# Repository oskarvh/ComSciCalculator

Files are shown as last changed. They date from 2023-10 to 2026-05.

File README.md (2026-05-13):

# Computer Scientist Calculator

The computer scientist calculator (comSciCalc) is a modern take on the HP 16C. 
It was born out of frustration of the terrible windows calculator, and the lack of nice alternatives. 

The comSciCalc consists of both hardware and software, where each component can be used independently or together; The hardware can act as a controller for the software, in which case the software is simply acting as a bigger display. 

## Setup
A list of the dependencies are shown below, divided into common dependencies, software (PC) dependencies and firmware dependencies for building, testing and running.

Apart from the non-source-code (e.g. compilers, python etc), all dependencies are pulled in either via git submodules (`git clone --recurse-submodules git@github.com:oskarvh/ComSciCalculator.git`), or at build time using CMake's `FetchContent` module.

### Common Dependencies
The common dependencies needs to be installed separately. 
- CMake version 3.27.7 or newer (`apt install cmake`)
- clang-format version 14.0.0 (`sudo apt install clang-format`)
- Doxygen 1.9.6 (`sudo apt install doxygen`)
- arm-none-eabi-gcc: Arm GNU Toolchain 13.3.1 or other compatible with rp2040 (`sudo apt install cmake gcc-arm-none-eabi libnewlib-arm-none-eabi build-essential`)
- CMake Tools (not required, but recommended if using VSCode)
- Python 3.10 or newer, with venv support (`apt install python3.<version>-venv`)

### Firmware Dependencies
- `arm-none-eabi` Compiler for the rp2040 (`sudo apt install gcc-arm-none-eabi libnewlib-arm-none-eabi build-essential`). Dependencies vary on system, see the [RPi Pico User Guide](https://datasheets.raspberrypi.com/pico/getting-started-with-pico.pdf)
- [OpenOCD for RP2040](https://github.com/raspberrypi/openocd) OpenOCD for RP2040. Unfortunately, the rp2040 requires its own installation of OpenOCD. See [this guide](https://github.com/SuperChange001/pico_debug_with_swd) for installation.
These dependencies are downloaded via CMake.
- [RP2040 Pico-SDK library](https://github.com/raspberrypi/pico-sdk) (included as a submodule)
- [Clay](https://github.com/oskarvh/clay) Forked Clay (C Layout) library with support for FT81x (included as submodule). Used both for PC and embedded GUI
- [FT800-FT813 library](https://github.com/RudolphRiedel/FT800-FT813) (included as a submodule)
- ComSciCalc Hardware

### Software Dependencies
These dependencies should be linked via CMake files and/or submodules.
- [Clay](https://github.com/oskarvh/clay) Forked Clay (C Layout) library with support for FT81x (included as submodule). Used both for PC and embedded GUI

### Test Dependencies
These dependencies are either included via Python or via submodules.
- Pytest
- [Unity](git@github.com:ThrowTheSwitch/Unity.git) Unity test tool (to be deprecated)
## BUILD
There are several targets that can be built in this repository:
- Firmware
- Software
- Tests
## Directory Structure
A brief overview of the directory structure can be found in this section. 

### `comSciCalcLib/`
This directory contains the comSciCalc library. This is technically a common library used here, but it has its own directory for clarity, since this is an essential part of the project. 

### `firmware/`
The firmware directory contains code required to build the firmware running on the comSciCalc hardware.
Note that this pulls in common dependencies as well. 
### `software/`
The software directory contains the code required to build the PC software. This uses some of the dependencies common to the firmware as well. 
### `test/`
The test directory contains all tests used both with firmware and software. 
Tests are divided into several categories.
#### `test/unit_tests/`
This directory contains unit tests, aimed to test granular components of the comSciCalc. 

If a new calculation function is added to the comSciCalc, then a unit test shall be written for that function. 
#### `test/feature_tests/`
This directory contains feature tests. These tests are aimed to test higher level functions of the comSciCalc, such as the solver and formatters. 

If a new high level feature is added in comSciCalc is created, then a feature test is expected.
#### `test/integration_tests/`
This is the highest level tests, where hardware and/or software is expected in the loop. 

If a new hardware revision is introduced which update interfaces, or if new high level functionality is created, a new integration test shall be written/existing test case updated.

### `utils/`
This is the utilities directory, and contain code which is not compiled/run/used at normal build time. For example, for creating bit-maps of fonts for the firmware, or other utilities which output is aimed at being checked in rather than built.

This directory is included as a developer help tool. 

### `hardware/`
This directory contain all the hardware source files, such as PCB design, mechanical design etc.

### `common/`
This directory contains code used in both `firmware/` and `software/`, and is placed outside either directory to have a common source, such that changes are reflected in both the firmware and the software. 

An example of this is the GUI, the link layer protocols etc. 

### `html/`
This directory contains the generated Doxygen HTML files. This is updated on a release basis, since the doxygen can be generated. Hence, it's not checked in regularly. 

## Contributing
Contributions are welcome, and this section aims to help a developer to add functionality to the comSciCalc.

There are several parts to the comSciCalc, and it's built with the aim of easily being able to add new features, such as new mathmatical operators.

### Adding an operator
An operator is any mathmatical function that can be called by the calculator, e.g. `+` or `AND()` etc.
An operator can have one or several arguments. 

# TODO list
This section contains stuff that needs doing. 
- Finish the documentation
- Restructure the repo to align with the structure in this readme.

---
# OLD STUFF (KEPT FOR REFERENCE, TO BE DELETED)
---
## Status of project
The software is mostly being worked on at the moment. A few iterations 
of the hardware has been made, but nothing has been ordered yet because some components are hard to get at the moment, along with the continuous change of heart when it comes to the hardware specs. 

The software is in a semi-stable phase at the moment. The core of the 
calculator, the software/comSciCalc_lib has had the ground work made. 
Fluffy features such as [doxygen](https://www.doxygen.nl/) and 
[clang formatter](https://clang.llvm.org/docs/ClangFormat.html) has been added as well. 

Unit testing has begun using the [Unity framework](https://github.com/ThrowTheSwitch/Unity). 

## Software

The software folder consists of two major code bases: comSciCalc_lib and unit_tests. 

The comSciCalc_lib is a library, currently compiled with GCC, which contains all the 
functions needed to input data, calculate and output result and formatted input. To 
compile and run the unit tests, run the following script:
```bash
./software/run_unit_tests.sh
```
To run the script in verbose mode, add the -V flag. To not compile the source, 
use flag -d. 
Incorrext flags will prompt the usage message:
```bash
$ ./run_unit_tests.sh -h
Usage: ./run_unit_tests.sh [-V verbose] [-d dont clean]
```
This will compile the comSciCalc_lib library and the unit test code (using Unity test framework) and run the tests. 

This very same library is intended to work on an embedded system, along with (hopefully) a 
PC GUI of sorts, so the code does not implement any fancy features. 

However, the test code uses some GCC specific preprocessor routines to initialize some of 
the arrays. 
## Software dependencies
On Windows 10, I am using :
* gcc (MinGW.org GCC-6.3.0-1) 6.3.0
* Clang version 12.0.0
* Doxygen 1.9.6
* Git bash

To pull unity into the repo, run:
```bash
git submodule update --init
```
## Documentation
To generate the docs, run the following:
```bash
cd software # Go to the software dir. 
doxygen doxygen_config
```
And the docs can be found in software/html/index.html

## Technical jargon
The core functionality of the calculator is: 
1. Handling input (valid checks, insertion)
2. Printing input
3. Converting from text to something that can be solved. 

Going through the list above, the input handling is done using a doubly linked
list, where the incoming char will be placed. Each entry has a pointer to 
the previous and a pointer to the next entry, along with data and meta data 
for that entry. The data is the actual input character, where the accepted chars
are a union between numerical and non-numerical input [0-9,a-f,(,),','] and
chars specific to the operators, found in comscicalc_operators.c. 

The meta data consists of e.g. base (i.e. hex, dec, bin), type of entry, pointer
to operator function (see below) and some more. See the docs for more info. 

Each operator has a unique char associated with it, along with some meta data of
its own, and a pointer to the function implementing the operator. 
The function is linked via function pointer that are casted left and right, 
but due to the way C let's a code handle pointer willy-nilly, this works out fine. 

When an input list is solved, it will re-use the entry list type above, but 
then each entry has a number associated with it, instead of a char. 
The solver will then go through this list and solve based on the function 
pointers and numbers entered. The next section will explain how to add 
a new operator. 

## Adding new operators
A new operator is added in the comscicalc_operators.[c,h] files, by adding a 
new entry to the ```operators``` table. The entry must consist of the following:
```
.inputChar = /* Associated operator character , e.g. '+'*/,
.opString = /* Null terminated string to be displayed during printing.  "+\0"*/,
.solvPrio = /* Solving priority, 0 is the highest. (see docs) */,
.bIncDepth = /* Boolean indicating if operators increase depth (=should it invoke a bracket) */,
.numArgs = /* Number of arguments. -1 if variable. Must be 2 if not depth increasing.  */,
.pFun = /* Pointer to the function associated with the operator */
```
Moreover, the operator function needs to be added to the comscicalc_operators.c 
and comscicalc_operators.h file as well. The operator function must follow this
 format:
 ```
int8_t calc_<NAME>(SUBRESULT_UINT *pResult, inputFormat_t inputFormat, int num_args, SUBRESULT_UINT *args);
 ```
Ideally the operator should support fixed and floating point, along with signed
and unsigned integer formats. But if for some reason this is impossible, then 
the function must return ```format_not_supported```

## Test coverage
The ```software/test_coverage.sh``` script will run a gcov analysis of the two main
library files: ```comscicalc.c``` and ```comscicalc_operators.c``` when running the test suite
in order to see what the code coverage is during the tests. This should ideally 
be close to 100% as it would indicate the code coverage is complete. 

Running this script will make a temporary folder under software called 
test_coverage, where the build files, gcov files and copies of the source files
are stored. 

Moreover, the script will print the code coverage for the two files being analyzed. 

To check which lines are being covered, run the ```test_coverage.sh``` script, go into the test_coverage directory and take a look in the ```*.c.gcov``` files. 
Each line with a ```#####``` mark has not been executed. 

With that information, additional tests can be added to the test suite to
ensure as good test coverage as possible.

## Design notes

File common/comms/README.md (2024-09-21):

# Computer Scientist Calculator Communication Protocol

This directory contains the unified communications protocol used by
the comSciCalc and PC software, where the units are assumed to be connected
by serial interface, e.g., UART or USB VCOM. 

## Background
The serial interface enables two-way communication between the host (computer) and the device (calculator). In the interest of not blasting the host with unwanted information, the device shall not communicate the state unless the host has explicitly connected to the device. 

Hence, there is a set of messages required to facilitate connection and disconnection between the host and the device. 

The intended host applications are: 
* PC GUI
* Hardware-in-the-loop feature testing

Once the device is connected to the host, there are multiple states and/or events that are allowed, for which the base set of changing settings and communicating with the solver are required. 
Since the calculator supports both user defined functions and programs, there is going to be a limit as to what the protocol can support, especially in regards to custom programs. 
As a guide, there shall be a set of graphical functions that will be supported, but there is no requirement for the user to only use these for a custom function. However, if those functions are used, the protocol shall allow compatibility with them. 

## Software stack
The OSI stack model for this interface is shown in Figure 1 below. 

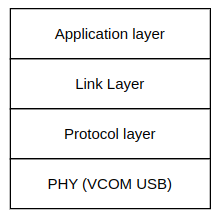
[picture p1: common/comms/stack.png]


*Figure 1. OSI stack model.*

The PHY is simply the USB VCOM layer, and is not specific in this document. 

The protocol layer specifies how the message bytes are arranged, and how the data and metadata is transferred between host and device. 

The link layer focuses on the body of the protocol layer message, and specifies how the binary data is decoded. 

Finally, the application layer is a purely software defined layer which consumes the link layer data, where the data itself is decoded. 

# Protocol Layer
This section documents the protocol and messages used by the serial interface. 
The message structure is shown in Figure 2 below. 

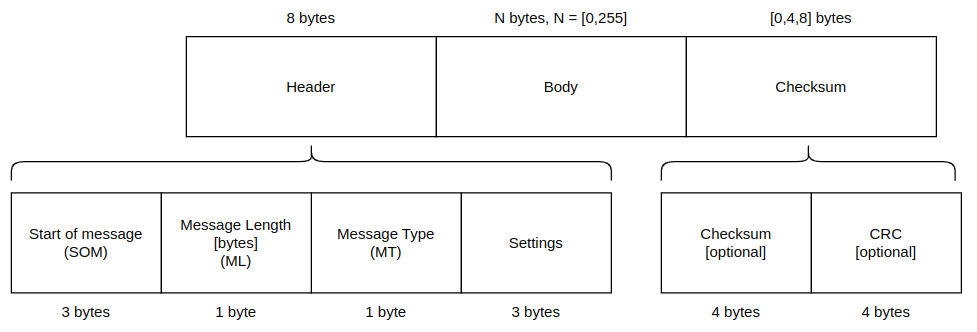
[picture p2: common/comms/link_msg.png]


*Figure 2. Message structure.*

As seen in Figure 2, the header consists of four fields, where the SOM indicates the start of communication. Since the device supports regular ASCII communication via a virtual COM port, to support context switching from ASCII reception to receiving this protocol, an [escape sequence](https://en.wikipedia.org/wiki/ANSI_escape_code) is used to differentiate the two. 
The APC (0x1B 5F 9F) sequence is re-used here, since it’s rarely implemented and can therefore easily be differentiated from other escape sequences. This field is not variable. 

The message length is indicating the length of the body, which is the data containing the message itself. Note that it’s indicating only the body length, not including the header or checksum. 

The message type indicates the type of message being sent (duh), where the message type indicates if the received message is a connection event, ack, data transfer etc.

The three byte settings field is partly used to indicate the settings used for the message, e.g., checksum configuration, body encoding and more, along with byte padding for the body. 

The body is the data itself, and the length in bytes of the data is decided by the ML field. From the protocol side, the body is handled just as binary data without any indications as to where that data is used, so the protocol does not differentiate depending on what data is being transferred. 

Finally, the checksum has two optional fields: Checksum and CRC, where either can be used. Both the checksum and CRC include both header and body. 

This format is used both from the host to device, and from device to host.

See Table 1 below for an overview of the different fields. 

*Table 1. OVerview of different fields*
Field | Accepted value(s) | Description
|:------ |:-----------| :---------------------------------------------------:|
SOM    | `0x1B5F9F` |   Start Of Message: This is a fixed value and <br>indicates the start of a message if prior <br>message has been terminated, or if timeout has been reached. 
ML | 0-255 | Message Length: Body length in Bytes
MT | `0x01` Data Transfer <br> `0x02` ACK <br>`0x04` NACK <br> `0x08` Retransmission <br>`0xF0` Reserved|Message Type: Type(s) of messages. A combination (OR) of the types are available. <br>Data Transfer: Transfer of data. Data will be forwarded to the link layer. <br>ACK: Acknowledgement. <br>NACK: Negative Acknowledgement.<br>Retransmission: This message is a retransmission of a previous message.
Settings | `0x000001` Use Checksum<br>`0x000002` Use CRC<br>`0x0000X0` Timeout<br>`0x000X00` Retries<br>`0xFF9004` Reserved<br> | Settings: These fields are bitwise ORed, and indicate protocol layer settings 
Body|Any|Data packets
Checksum|Any|Checksum (algorithm TBD)
CRC|Any|CRC (algorithm TBD)

## Message Types
The message types indicate the message being sent, and a message containing data can also contain information regarding the last message(ACK,NACK). 

### Data Transfer
If the message type is data transfer, it is assumed but not guaranteed that the body contains data. However, if the data transfer bit is 0, the body must be empty.

### Acknowledgement
If the message type ACK bit is set, it means that the last message was received correctly. If no previous message exists (e.g. connection event), the ACK and NACK can be set to 0. 
The NACK bit aims to indicate that the last message sent had an error. This could indicate that the connection was severed or interrupted, CRC error or any other error corrupting the last message. 

Note that a data transfer can contain an ACK or NACK, meaning that the reception of a message containing data can acknowledge the previous message sent.

A received ACK or NACK is always in relation to the last transmitted message, so full duplex support is limited. Each message must be acknowledged before the next message can be transmitted. 

### Retransmission
If a NACK is received, the transmitter shall retransmit the previous message with the retransmission bit set. Retransmission of the previous message shall be supported by both the device and host. 
The retransmission needs to be acknowledged just like any data transfer, and the bit only indicates that a retransmission is occurring. 

Note that retransmissions here are only valid for issues on the protocol layer, and do not need to be communicated from the link layer. If the link layer needs a retransmission, it has the capability to request it as well, but that is not covered here.

## Settings
The settings simply indicate the settings to be used for the packet. 

### Use Checksum
If “use checksum” is set, then checksum shall be transmitted, received and checked on 
reception. A faulty received checksum shall produce a NACK on the next transmitted message. 

### Use CRC
If “use CRC” is set, then CRCll be transmitted, received and checked on 
reception. A faulty received CRC which cannot recover the data shall produce a NACK on the next transmitted message. 

### Timeout
The timeout section indicates the time to wait for an acknowledgement. No new message can be transmitted until the previous message has been acknowledged, so a timeout event is treated as a NACK. The values in the timeout field are in relation to the LUT in Table 2 below, and as seen the timeout value increases with a factor 10 per value of bits 0-3, and bits 4-15 indicate the multiplier. The final timeout value is the multiplier times the base. 
E.g. 50 ms is multiplier 5 and base 10 ms. 

*Table 2. Timeout bases and multipliers*
Timeout setting value | Timeout
|:------------------- | :-----------:|
Bits 0-3: `0x0`         | base: 1 ms
Bits 0-3: `0x1`         |base: 10 ms
Bits 0-3: `0x2`         |base: 100 ms
Bits 0-3: `0x3`         |base: 1000 ms
Bits 4-15: `0x1`        |multiplier: 1
Bits 4-15: `0x2`        |multiplier: 2
Bits 4-15: `0x3`        |multiplier: 3
Bits 4-15: `0x4`        |multiplier: 4
Bits 4-15: `0x5`        |multiplier: 5
Bits 4-15: `0x6`        |multiplier: 6
Bits 4-15: `0x7`        |multiplier: 7
Bits 4-15: `0x8`        |multiplier: 8
Bits 4-15: `0x9`        |multiplier: 9
Bits 4-15: `0xA-0xC`    |Reserved

The timeout is on a per message basis, so the transmitter tells how long it will wait for an acknowledgement. There is no algorithm for setting this rate based on retransmission, other than it should be set to as low as possible without causing retransmissions. 

### Retries
Retries simply indicate how many retransmissions can be made before a connection is severed. 
If the retries number messages are not successfully acknowledged, the connection is assumed to be severed, and a connection event is required to establish a new connection. 

As of writing this spec, the default number of retries is set to be 3. 
If a retransmission is made, either by NACK or timeout, this field decreases, and if retries = 0 and the message is not ACKed, the connection will be severed. 
It is also a good idea, although not enforced, to increase the timeout per decrementation of this field. This feature is left to the implementer. 

## Data Flow
The protocol itself, i.e. how data is flowing back and forth, is really very simple as it’s done over cable, meaning that it can be assumed that the packet loss is very small. 
There is no guarantee that data will arrive, nor arrive in sequence, but since it’s a point to point protocol that can easily be kept track of by the devices themselves. Since no PHY level interaction is available, ready to send and ready to receive can be assumed to be handled by the PHY already. Moreover, it is assumed that both host and device have sufficiently large receive buffers to hold a message while it’s being received. 

The following sections explain connection, disconnection, retransmission and regular transmission. 
Note that even though the physical layer might support full duplex, this protocol does not support full duplex, rather it’s simplex, where a receiver can assume to empty its receive buffer after a successful reception, and not lose any incoming messages. 

The protocol layer receives byte-per-byte, where it’s considered the largest byte to be first. So the first byte being received in any transmission is the SOM escape (27) byte. 

### Connection event
A connection can be initiated by any device, and is indicated by the initiator sending a message with data transfer = 0, ack = 0 and nack = 0. 
A connection is created if the initiator receives an acknowledged message (ACK=1, NACK=0) within the timeout period. 
Note that the connection by the responder is allowed to contain data. 

A connection event is the only message that can be transmitted without either an ACK or NACK, all messages after the initiator message must contain ACK or NACK. 

The retries section is not required to decrement if the initiator resends the connection event message. 

If a connection event message is NACKed, a connection cannot be made, and the initiator can retry. 

### Disconnection
A disconnection does not have a specified sequence, rather, if the retries counter expires (i.e. a message sent with retries = 0 is not ACKed), the connection is severed. So to sever a connection a device simply needs to stop responding, or NACK the number of retries. 

### Retransmission 
A retransmission shall happen after a message was unsuccessfully received, either by not being ACKed within the timeout, or not receiving a message within the specified timeout. 
If a retransmission is made, the retry counter shall be decremented. If a message is sent with retries = 0, and not ACKed, the connection is severed and the message cannot be assumed to be received. 
If a retransmission is ACKed, the retries counter can be reset to the default value. 

If a lot of retransmissions are observed, then it could be a good idea to increase the timeout, but it’s not enforced. 

### Timeout
A timeout is signified by a message not being received within the timeout period, as specified in the settings section. 

The time is counted from when the transmission is completed, i.e. the last bit is sent to the PHY layer, until the next header has been fully received. Note that the body does not need to be received to stop the timeout timer, since the body has variable length, while the header has a fixed length and is therefore more deterministic. 

Note that any reception of a header will stop the timer, so if the header includes an error it does not count towards a timeout error. Another way of looking at timeout is that the timeout timer shall stop after 8 bytes have been received.

### Inability to receive data
If the data receive queue is full, the protocol layer shall treat this as an inability to receive messages, meaning that if data is dropped due to insufficient queue space, a NACK is sent and the previous message is retransmitted and the queueing is retried the next time that same message is received. 
Inability to receive data due to queue size issues can cause a severed connection. 

### Idle data transmission
If no data is available in the transmission queue, then no data will be sent with the next message at the time of evaluating. 

If there is no data transmitted for a duration of time, i.e. the device and host are both idle, the timeout can be extended such that less data is being sent over the physical layer.
Since the timeout is decided by the transmitted message, the transmitter decides what the timeout should be, so some preemption can be made here. 
The receiver is allowed to wait to transmit a response, as long as it’s within the timeout.

# Link Layer (WIP)
The link layer focuses on the data of the packet, i.e. the body of the protocol layer. 
The link layer receives data from the protocol layer, but does not have control over the protocol layer, so cannot request retransmissions by the protocol layer. 
However, the protocol layer tries its best to verify that all bytes have been received, such that the integrity of the data received by the link layer is good. 
It’s not foolproof but the checksum and CRC should indicate that the received data is at least intact. 
The protocol layer does not guarantee that the received data is sequential though, so steps have to be taken in the link layer to request retransmissions if needed. 

Note that the link layer and protocol layer is separated such that the link layer is protocol agnostic, and it is simply a way of translating the data from just received bits into something that can be used by the comSciCalc device and host. 
Hence, the link layer cannot have any say into what the protocol layer is doing here, and should there be an update in the protocol layer, or change of protocol overall, the link layer should be reusable. 

The link layer data consists of two parts: a header and the raw data itself, and as opposed to the link layer/protocol layer separation, the link layer and application layer does not easily separate. This is due to the construction of the link layer header. 

The link layer receives the significant byte first from the protocol layer, or if received as a pointer, the pointer points to the start of the header. 
Hence, the link layer receives data and length of that data from the protocol layer, and can read the data. There is no flow control between the protocol layer and link layer, other than what can be facilitated by regular queues. 
Moreover, transmissions from the link layer can be handled by queues, not specified here, although with the current implementation of the comSciCalc firmware it’s using FreeRTOS.
The queue size is fixed at compile time, and shared between the protocol layer and link layer. 

## Header
The header decides what the intention of the data is, and thereby how it should be decoded. 
Data here can be, per default, any one of the following types:
* ComSciCalc State
  * Always sent from the device to the host
  * This is mainly aimed to mirror the screen on the calculator to the PC
* ComSciCalc input
  * Always sent from the host to the device
  * This is input to the calculator, in the form of numbers
* Request for data
  * This is a request for the devices internal states
  * This can be used to synchronize the device and the host
* Response for data
  * This is the response for the request
* New program
  * There is space in the flash for custom programs, accessible via the menu
  * This command sends the binary data and where to store it, along with metadata such that the program can be accessible via the menu.

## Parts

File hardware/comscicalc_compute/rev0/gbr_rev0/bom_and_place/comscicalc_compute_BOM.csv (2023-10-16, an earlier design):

Comment | Designator | Footprint | LCSC
22pF | C1,C7 | Capacitor_SMD:C_0402_1005Metric | C1555
10uF | C12,C19,C25 | Capacitor_SMD:C_0805_2012Metric | C15850
22uF | C13,C15,C16,C17,C24,C27,C29 | Capacitor_SMD:C_0805_2012Metric | C45783
1uF | C14 | Capacitor_SMD:C_0603_1608Metric | C15849
100nF | C2,C3,C4,C5,C6,C8,C9,C10,C11,C18,C21,C23,C31,C33,C34,C35,C36 | Capacitor_SMD:C_0402_1005Metric | C1525
4.7uF | C20,C32 | Capacitor_SMD:C_0603_1608Metric | C19666
10nF | C22,C26,C28,C30 | Capacitor_SMD:C_0402_1005Metric | C15195
NSR0240P2T5G | D1 | SamacSys_Parts:SODFL1006X40N | C896425
BLM21PG300SN1D | FB1,FB2 | Resistor_SMD:R_0805_2012Metric | C16903
ACM2012-361-2P-T002 | FL1 | SamacSys_Parts:ACM20121022PT001 | C87126
R7FA4M3AF3CFM#AA0 | IC1 | SamacSys_Parts:QFP50P1200X1200X170-64N | C3230355
TPS92360DCKR | IC2 | SOT65P210X110-5N | C2928788
AP62300TWU-7 | IC3 | SOT95P280X100-6N | C1883519
FT811Q-T | IC4 | SamacSys_Parts:QFN50P700X700X90-49N-D | C3823896
Conn_02x14_Odd_Even | J1,J2 | Connector_PinHeader_2.54mm:PinHeader_2x14_P2.54mm_Vertical_SMD | DNM
USB4110-GF-A | J3 | USB4110GFA | C5143397
4-1734839-0 | J4 | SamacSys_Parts:4-1734839-0 | C590939
ASPI-0403S-1R5M-T | L1 | SamacSys_Parts:ASPI0403S332MT | C187216
3.3uH | L2 | VLS5045EX-3R3N:IND_VLS5045EX-3R3N | C307875
DNM | R1,R2,R9,R10,R11,R12,R13,R23,R50 | Resistor_SMD:R_0402_1005Metric | DNM
5.1k | R14,R18 | Resistor_SMD:R_0402_1005Metric | C258132
22R | R15 | Resistor_SMD:R_0402_1005Metric | C25092
33.2k | R16 | Resistor_SMD:R_0402_1005Metric | C400623
33R | R25,R26,R27,R28,R29,R30,R31,R32,R33,R34,R35,R36,R38,R39,R40,R41,R42,R43,R44,R45,R46,R47,R48 | Resistor_SMD:R_0402_1005Metric | C25105
0R | R3,R7,R22,R37 | Resistor_SMD:R_0402_1005Metric | C174180
10k | R4,R6,R8,R17,R21,R24,R49 | Resistor_SMD:R_0402_1005Metric | C140214
1k | R5,R19,R20 | Resistor_SMD:R_0402_1005Metric | C279981
SSSS211603 | SW1,SW2 | SamacSys_Parts:SSSS211603 | C125040
USBLC6-2SC6 | U1 | Package_TO_SOT_SMD:SOT-23-6 | C5250994
FL2400022 | Y1 | SamacSys_Parts:FL2400022 | C1985606
X1G004171001800 | Y2 | SamacSys_Parts:X1G004171001800 | C255991

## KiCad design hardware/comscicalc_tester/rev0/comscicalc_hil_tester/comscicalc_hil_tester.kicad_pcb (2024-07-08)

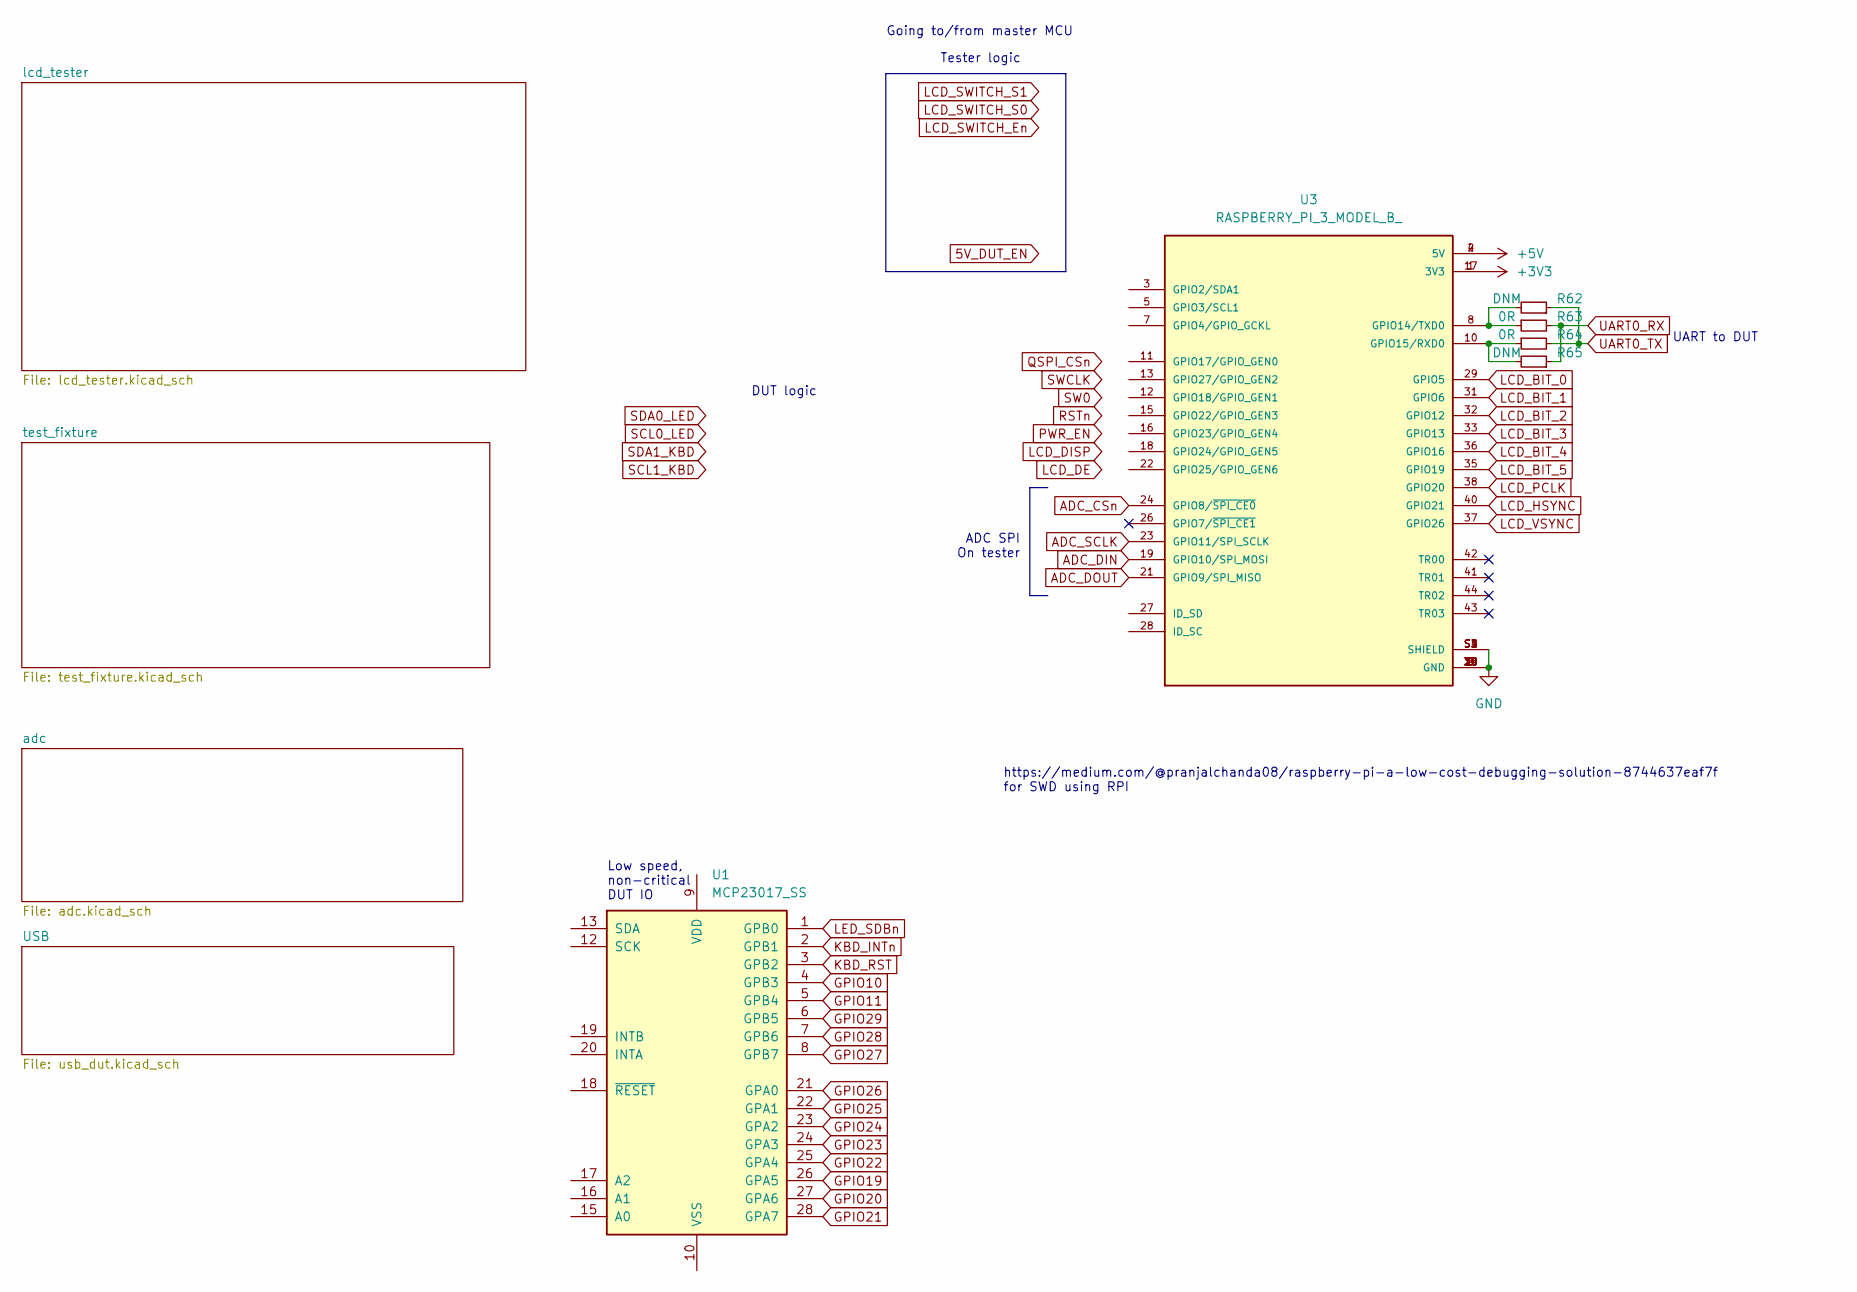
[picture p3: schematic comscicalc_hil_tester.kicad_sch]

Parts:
R62, R65: DNM; R_0603_1608Metric
R63, R64: 0R; R_0402_1005Metric
U1: MCP23017_SS; SSOP-28_5.3x10.2mm_P0.65mm
U3: RASPBERRY_PI_3_MODEL_B_; MODULE_RASPBERRY_PI_3_MODEL_B_; PARTREV N/A

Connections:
+3V3: U3.1 (3V3), U3.17 (3V3); also elsewhere on the board
+5V: U3.2 (5V), U3.4 (5V); also elsewhere on the board
ADC_CSn: U3.24 (GPIO8/~SPI_CE0); also elsewhere on the board
ADC_DIN: U3.19 (GPIO10/SPI_MOSI); also elsewhere on the board
ADC_DOUT: U3.21 (GPIO9/SPI_MISO); also elsewhere on the board
ADC_SCLK: U3.23 (GPIO11/SPI_SCLK); also elsewhere on the board
GND: U3.6 (GND), U3.9 (GND), U3.14 (GND), U3.20 (GND), U3.25 (GND), U3.30 (GND), U3.34 (GND), U3.39 (GND), U3.S1 (SHIELD), U3.S2 (SHIELD), U3.S3 (SHIELD), U3.S4 (SHIELD); also elsewhere on the board
GPIO10: U1.4 (GPB3); also elsewhere on the board
GPIO11: U1.5 (GPB4); also elsewhere on the board
GPIO19: U1.26 (GPA5); also elsewhere on the board
GPIO20: U1.27 (GPA6); also elsewhere on the board
GPIO21: U1.28 (GPA7); also elsewhere on the board
GPIO22: U1.25 (GPA4); also elsewhere on the board
GPIO23: U1.24 (GPA3); also elsewhere on the board
GPIO24: U1.23 (GPA2); also elsewhere on the board
GPIO25: U1.22 (GPA1); also elsewhere on the board
GPIO26: U1.21 (GPA0); also elsewhere on the board
GPIO27: U1.8 (GPB7); also elsewhere on the board
GPIO28: U1.7 (GPB6); also elsewhere on the board
GPIO29: U1.6 (GPB5); also elsewhere on the board
KBD_INTn: U1.2 (GPB1); also elsewhere on the board
KBD_RST: U1.3 (GPB2); also elsewhere on the board
LED_SDBn: U1.1 (GPB0); also elsewhere on the board
unnamed: R62.2, R63.1, U3.8 (GPIO14/TXD0)
unnamed: R64.1, R65.2, U3.10 (GPIO15/RXD0)
UART0_RX: R63.2, R65.1; also elsewhere on the board
UART0_TX: R62.1, R64.2; also elsewhere on the board

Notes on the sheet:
Tester logic
Low speed, non-critical DUT IO
https://medium.com/@pranjalchanda08/raspberry-pi-a-low-cost-debugging-solution-8744637eaf7f for SWD using RPI
Going to/from master MCU
ADC SPI On tester
DUT logic
UART to DUT

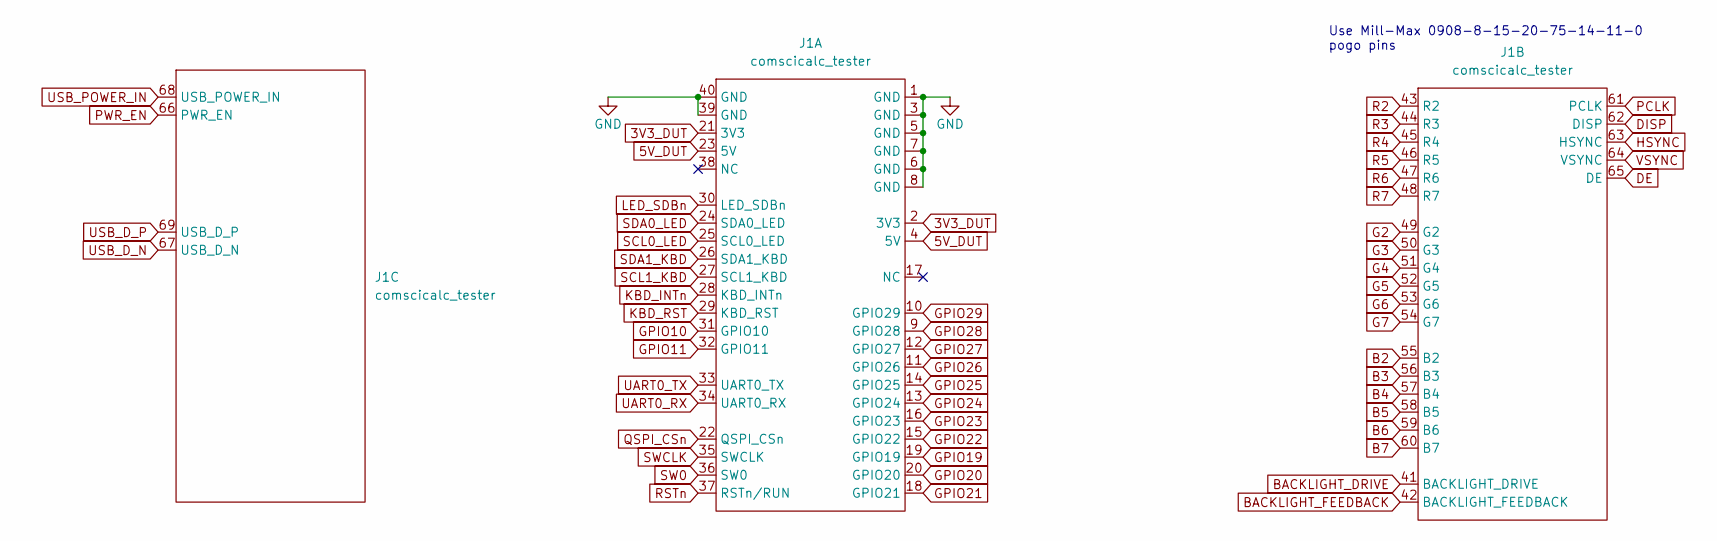
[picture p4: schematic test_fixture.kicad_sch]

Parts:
J1: comscicalc_tester; tester_footprint

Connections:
3V3_DUT: J1.2 (3V3), J1.21 (3V3); also elsewhere on the board
5V_DUT: J1.4 (5V), J1.23 (5V); also elsewhere on the board
B2: J1.55 (B2); also elsewhere on the board
B3: J1.56 (B3); also elsewhere on the board
B4: J1.57 (B4); also elsewhere on the board
B5: J1.58 (B5); also elsewhere on the board
B6: J1.59 (B6); also elsewhere on the board
B7: J1.60 (B7); also elsewhere on the board
BACKLIGHT_DRIVE: J1.41 (BACKLIGHT_DRIVE); also elsewhere on the board
BACKLIGHT_FEEDBACK: J1.42 (BACKLIGHT_FEEDBACK); also elsewhere on the board
DE: J1.65 (DE); also elsewhere on the board
DISP: J1.62 (DISP); also elsewhere on the board
G2: J1.49 (G2); also elsewhere on the board
G3: J1.50 (G3); also elsewhere on the board
G4: J1.51 (G4); also elsewhere on the board
G5: J1.52 (G5); also elsewhere on the board
G6: J1.53 (G6); also elsewhere on the board
G7: J1.54 (G7); also elsewhere on the board
GND: J1.1 (GND), J1.3 (GND), J1.5 (GND), J1.6 (GND), J1.7 (GND), J1.8 (GND), J1.39 (GND), J1.40 (GND); also elsewhere on the board
GPIO10: J1.31 (GPIO10); also elsewhere on the board
GPIO11: J1.32 (GPIO11); also elsewhere on the board
GPIO19: J1.19 (GPIO19); also elsewhere on the board
GPIO20: J1.20 (GPIO20); also elsewhere on the board
GPIO21: J1.18 (GPIO21); also elsewhere on the board
GPIO22: J1.15 (GPIO22); also elsewhere on the board
GPIO23: J1.16 (GPIO23); also elsewhere on the board
GPIO24: J1.13 (GPIO24); also elsewhere on the board
GPIO25: J1.14 (GPIO25); also elsewhere on the board
GPIO26: J1.11 (GPIO26); also elsewhere on the board
GPIO27: J1.12 (GPIO27); also elsewhere on the board
GPIO28: J1.9 (GPIO28); also elsewhere on the board
GPIO29: J1.10 (GPIO29); also elsewhere on the board
HSYNC: J1.63 (HSYNC); also elsewhere on the board
KBD_INTn: J1.28 (KBD_INTn); also elsewhere on the board
KBD_RST: J1.29 (KBD_RST); also elsewhere on the board
LED_SDBn: J1.30 (LED_SDBn); also elsewhere on the board
PCLK: J1.61 (PCLK); also elsewhere on the board
PWR_EN: J1.66 (PWR_EN)
QSPI_CSn: J1.22 (QSPI_CSn)
R2: J1.43 (R2); also elsewhere on the board
R3: J1.44 (R3); also elsewhere on the board
R4: J1.45 (R4); also elsewhere on the board
R5: J1.46 (R5); also elsewhere on the board
R6: J1.47 (R6); also elsewhere on the board
R7: J1.48 (R7); also elsewhere on the board
RSTn: J1.37 (RSTn/RUN)
SCL0_LED: J1.25 (SCL0_LED)
SCL1_KBD: J1.27 (SCL1_KBD)
SDA0_LED: J1.24 (SDA0_LED)
SDA1_KBD: J1.26 (SDA1_KBD)
SW0: J1.36 (SW0)
SWCLK: J1.35 (SWCLK)
UART0_RX: J1.34 (UART0_RX); also elsewhere on the board
UART0_TX: J1.33 (UART0_TX); also elsewhere on the board
USB_D_N: J1.67 (USB_D_N); also elsewhere on the board
USB_D_P: J1.69 (USB_D_P); also elsewhere on the board
USB_POWER_IN: J1.68 (USB_POWER_IN); also elsewhere on the board
VSYNC: J1.64 (VSYNC); also elsewhere on the board

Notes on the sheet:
Use Mill-Max 0908-8-15-20-75-14-11-0 pogo pins

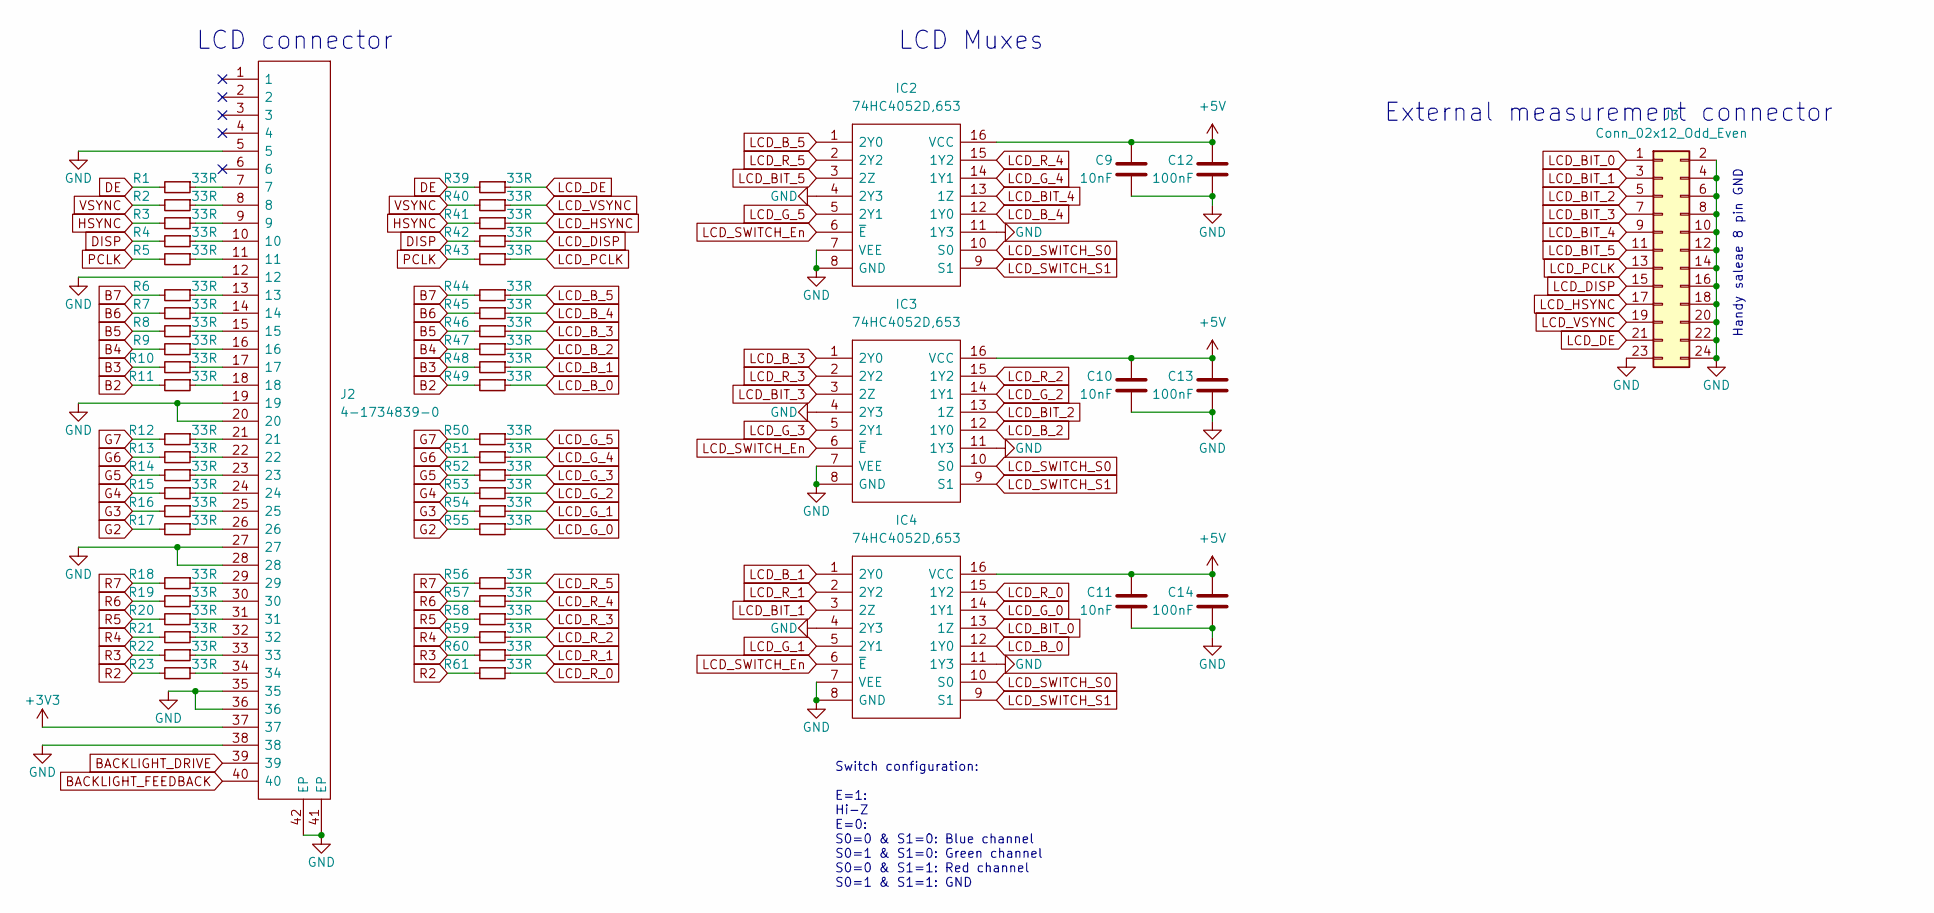
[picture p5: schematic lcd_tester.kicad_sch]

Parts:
C9, C10, C11: 10nF; C_0402_1005Metric
C12, C13, C14: 100nF; C_0402_1005Metric
IC2, IC3, IC4: 74HC4052D,653; 74HC4052D653; Mouser Part Number 771-74HC4052D-T
J2: 4-1734839-0; Mouser Part Number 571-4-1734839-0
J3: Conn_02x12_Odd_Even; PinHeader_2x12_P2.54mm_Vertical_SMD
R1, R2, R3, R4, R5, R6, R7, R8, R9, R10, R11, R12, R13, R14, R15, R16, R17, R18, R19, R20, R21, R22, R23, R39, R40, R41, R42, R43, R44, R45, R46, R47, R48, R49, R50, R51, R52, R53, R54, R55, R56, R57, R58, R59, R60, R61: 33R; R_0402_1005Metric

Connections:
+3V3: J2.37; also elsewhere on the board
+5V: C9.2, C10.2, C11.2, C12.2, C13.2, C14.2, IC2.16 (VCC), IC3.16 (VCC), IC4.16 (VCC); also elsewhere on the board
B2: R11.2, R49.2; also elsewhere on the board
B3: R10.2, R48.2; also elsewhere on the board
B4: R9.2, R47.2; also elsewhere on the board
B5: R8.2, R46.2; also elsewhere on the board
B6: R7.2, R45.2; also elsewhere on the board
B7: R6.2, R44.2; also elsewhere on the board
BACKLIGHT_DRIVE: J2.39; also elsewhere on the board
BACKLIGHT_FEEDBACK: J2.40; also elsewhere on the board
DE: R1.2, R39.2; also elsewhere on the board
DISP: R4.2, R42.2; also elsewhere on the board
G2: R17.2, R55.2; also elsewhere on the board
G3: R16.2, R54.2; also elsewhere on the board
G4: R15.2, R53.2; also elsewhere on the board
G5: R14.2, R52.2; also elsewhere on the board
G6: R13.2, R51.2; also elsewhere on the board
G7: R12.2, R50.2; also elsewhere on the board
GND: C9.1, C10.1, C11.1, C12.1, C13.1, C14.1, IC2.4 (2Y3), IC2.7 (VEE), IC2.8 (GND), IC2.11 (1Y3), IC3.4 (2Y3), IC3.7 (VEE), IC3.8 (GND), IC3.11 (1Y3), IC4.4 (2Y3), IC4.7 (VEE), IC4.8 (GND), IC4.11 (1Y3), J2.5, J2.12, J2.19, J2.20, J2.27, J2.28, J2.35, J2.36, J2.38, J2.41 (EP), J2.42 (EP), J3.2, J3.4, J3.6, J3.8, J3.10, J3.12, J3.14, J3.16, J3.18, J3.20, J3.22, J3.23, J3.24; also elsewhere on the board
HSYNC: R3.2, R41.2; also elsewhere on the board
LCD_BIT_0: IC4.13 (1Z), J3.1
LCD_BIT_1: IC4.3 (2Z), J3.3
LCD_BIT_2: IC3.13 (1Z), J3.5
LCD_BIT_3: IC3.3 (2Z), J3.7
LCD_BIT_4: IC2.13 (1Z), J3.9
LCD_BIT_5: IC2.3 (2Z), J3.11
LCD_B_0: IC4.12 (1Y0), R49.1
LCD_B_1: IC4.1 (2Y0), R48.1
LCD_B_2: IC3.12 (1Y0), R47.1
LCD_B_3: IC3.1 (2Y0), R46.1
LCD_B_4: IC2.12 (1Y0), R45.1
LCD_B_5: IC2.1 (2Y0), R44.1
LCD_DE: J3.21, R39.1
LCD_DISP: J3.15, R42.1
LCD_G_0: IC4.14 (1Y1), R55.1
LCD_G_1: IC4.5 (2Y1), R54.1
LCD_G_2: IC3.14 (1Y1), R53.1
LCD_G_3: IC3.5 (2Y1), R52.1
LCD_G_4: IC2.14 (1Y1), R51.1
LCD_G_5: IC2.5 (2Y1), R50.1
LCD_HSYNC: J3.17, R41.1
LCD_PCLK: J3.13, R43.1
LCD_R_0: IC4.15 (1Y2), R61.1
LCD_R_1: IC4.2 (2Y2), R60.1
LCD_R_2: IC3.15 (1Y2), R59.1
LCD_R_3: IC3.2 (2Y2), R58.1
LCD_R_4: IC2.15 (1Y2), R57.1
LCD_R_5: IC2.2 (2Y2), R56.1
LCD_SWITCH_En: IC2.6 (~E), IC3.6 (~E), IC4.6 (~E)
LCD_SWITCH_S0: IC2.10 (S0), IC3.10 (S0), IC4.10 (S0)
LCD_SWITCH_S1: IC2.9 (S1), IC3.9 (S1), IC4.9 (S1)
LCD_VSYNC: J3.19, R40.1
unnamed: J2.7, R1.1
unnamed: J2.8, R2.1
unnamed: J2.9, R3.1
unnamed: J2.10, R4.1
unnamed: J2.11, R5.1
unnamed: J2.13, R6.1
unnamed: J2.14, R7.1
unnamed: J2.15, R8.1
unnamed: J2.16, R9.1
unnamed: J2.17, R10.1
unnamed: J2.18, R11.1
unnamed: J2.21, R12.1
unnamed: J2.22, R13.1
unnamed: J2.23, R14.1
unnamed: J2.24, R15.1
unnamed: J2.25, R16.1
unnamed: J2.26, R17.1
unnamed: J2.29, R18.1
unnamed: J2.30, R19.1
unnamed: J2.31, R20.1
unnamed: J2.32, R21.1
unnamed: J2.33, R22.1
unnamed: J2.34, R23.1
PCLK: R5.2, R43.2; also elsewhere on the board
R2: R23.2, R61.2; also elsewhere on the board
R3: R22.2, R60.2; also elsewhere on the board
R4: R21.2, R59.2; also elsewhere on the board
R5: R20.2, R58.2; also elsewhere on the board
R6: R19.2, R57.2; also elsewhere on the board
R7: R18.2, R56.2; also elsewhere on the board
VSYNC: R2.2, R40.2; also elsewhere on the board

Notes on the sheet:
External measurement connector
LCD connector
Switch configuration: E=1: Hi-Z E=0: S0=0 & S1=0: Blue channel S0=1 & S1=0: Green channel S0=0 & S1=1: Red channel S0=1 & S1=1: GND
Handy saleae 8 pin GND
LCD Muxes

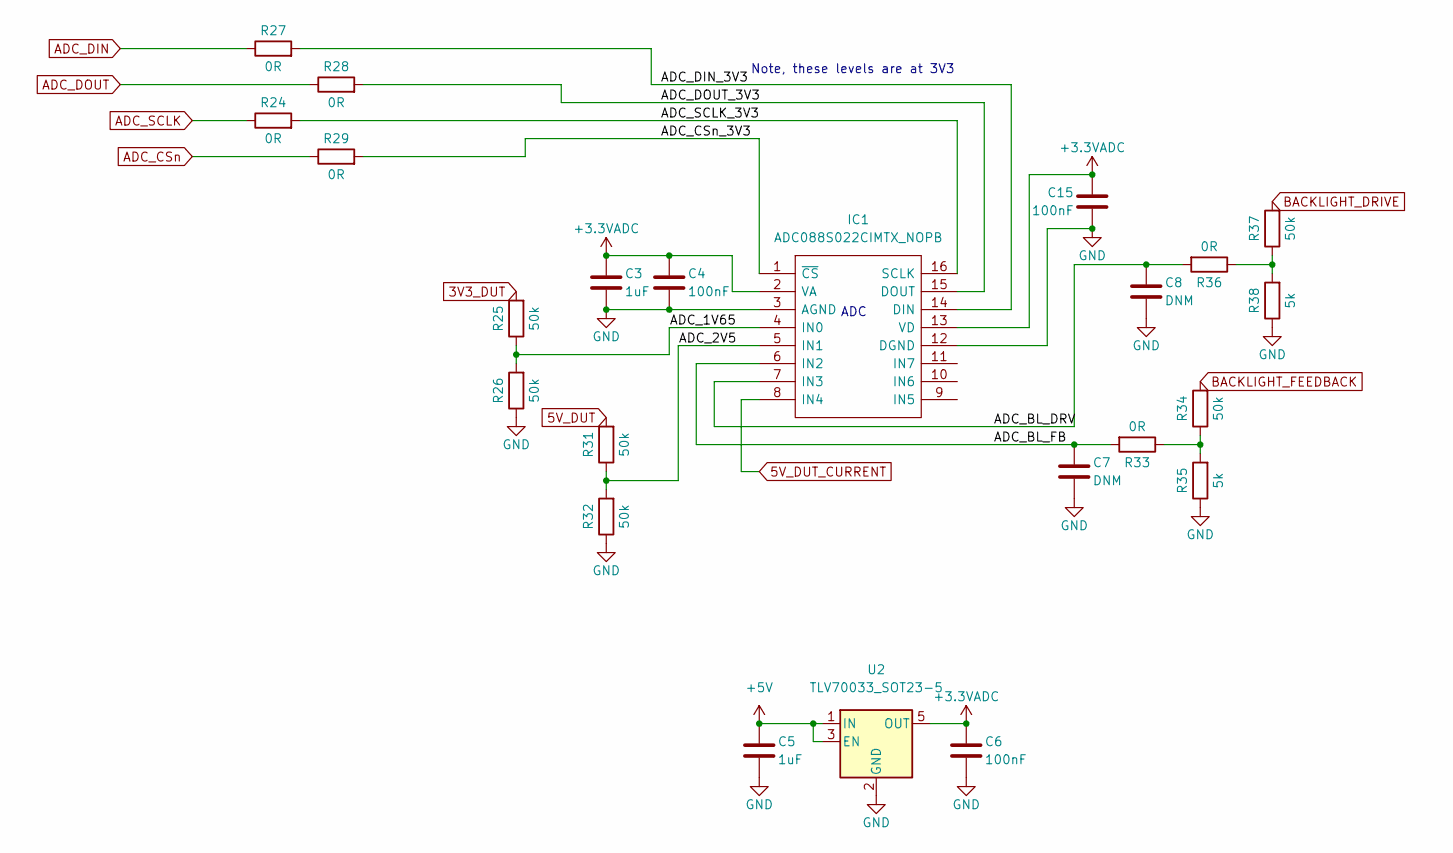
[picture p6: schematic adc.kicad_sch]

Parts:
C3, C5: 1uF; C_0603_1608Metric
C4, C6, C15: 100nF; C_0402_1005Metric
C7, C8: DNM; C_0603_1608Metric
IC1: ADC088S022CIMTX_NOPB; SOP65P640X120-16N; Mouser Part Number 926-A088S022CIMTXNPB
R24, R27, R28, R29, R33, R36: 0R; R_0402_1005Metric
R25, R26, R31, R32, R34, R37: 50k; R_0402_1005Metric
R35, R38: 5k; R_0402_1005Metric
U2: TLV70033_SOT23-5; SOT-23-5

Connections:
3V3_DUT: R25.2; also elsewhere on the board
5V_DUT: R31.2; also elsewhere on the board
5V_DUT_CURRENT: IC1.8 (IN4); also elsewhere on the board
+3.3VADC: C3.2, C4.2, C6.2, C15.2, IC1.2 (VA), IC1.13 (VD), U2.5 (OUT)
+5V: C5.2, U2.1 (IN), U2.3 (EN); also elsewhere on the board
/adc/ADC_1V65: IC1.4 (IN0), R25.1, R26.2
/adc/ADC_2V5: IC1.5 (IN1), R31.1, R32.2
/adc/ADC_BL_DRV: C8.2, IC1.7 (IN3), R36.2
/adc/ADC_BL_FB: C7.2, IC1.6 (IN2), R33.2
/adc/ADC_CSn_3V3: IC1.1 (~CS), R29.2
/adc/ADC_DIN_3V3: IC1.14 (DIN), R27.2
/adc/ADC_DOUT_3V3: IC1.15 (DOUT), R28.2
/adc/ADC_SCLK_3V3: IC1.16 (SCLK), R24.2
ADC_CSn: R29.1; also elsewhere on the board
ADC_DIN: R27.1; also elsewhere on the board
ADC_DOUT: R28.1; also elsewhere on the board
ADC_SCLK: R24.1; also elsewhere on the board
BACKLIGHT_DRIVE: R37.2; also elsewhere on the board
BACKLIGHT_FEEDBACK: R34.2; also elsewhere on the board
GND: C3.1, C4.1, C5.1, C6.1, C7.1, C8.1, C15.1, IC1.3 (AGND), IC1.12 (DGND), R26.1, R32.1, R35.1, R38.1, U2.2 (GND); also elsewhere on the board
unnamed: R33.1, R34.1, R35.2
unnamed: R36.1, R37.1, R38.2

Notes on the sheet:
Note, these levels are at 3V3
ADC

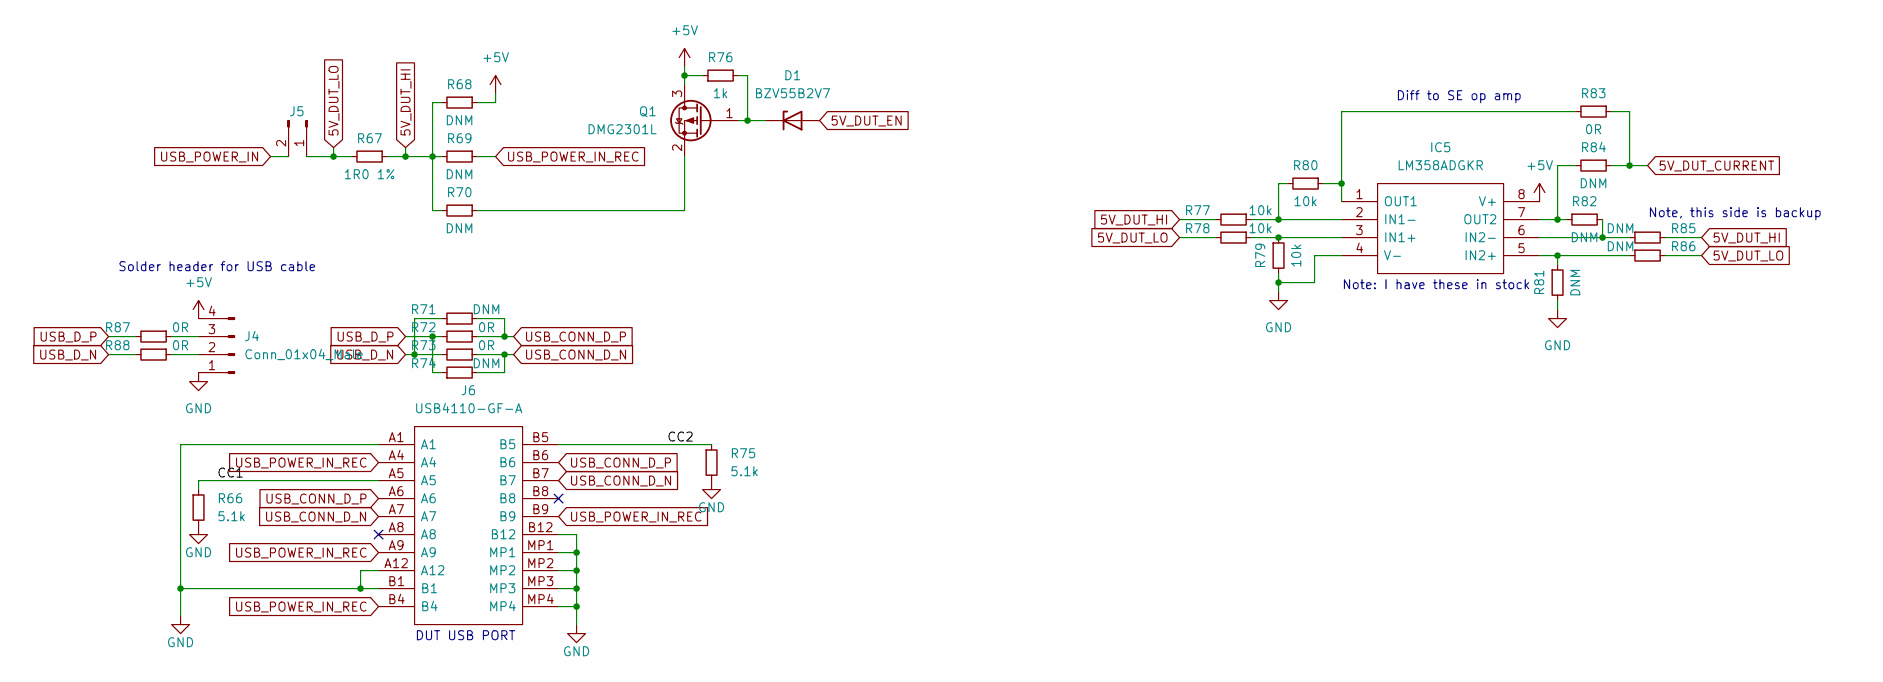
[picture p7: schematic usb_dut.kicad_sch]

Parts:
D1: BZV55B2V7; D_MiniMELF
IC5: LM358ADGKR; SOP65P490X110-8N; Mouser Part Number 595-LM358ADGKR
J4: Conn_01x04_Male; PinHeader_1x04_P2.54mm_Vertical
J5: Conn_01x02_Male; PinHeader_1x02_P2.54mm_Vertical
J6: USB4110-GF-A; USB4110GFA; Mouser Part Number 640-USB4110-GF-A
Q1: DMG2301L; SOT-23
R66, R75: 5.1k; R_0402_1005Metric; LCSC C258132
R67: 1R0 1%; R_0603_1608Metric
R68, R69, R70, R81, R82, R84, R85, R86: DNM; R_0402_1005Metric
R71, R74: DNM; R_0603_1608Metric
R72, R73, R83, R87, R88: 0R; R_0402_1005Metric
R76: 1k; R_0402_1005Metric
R77, R78, R79, R80: 10k; R_0402_1005Metric

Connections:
5V_DUT_CURRENT: R83.1, R84.1; also elsewhere on the board
5V_DUT_EN: D1.2 (A)
5V_DUT_HI: R67.1, R68.2, R69.2, R70.2, R77.2, R85.2
5V_DUT_LO: J5.1, R67.2, R78.2, R86.2
+5V: IC5.8 (V+), J4.4, Q1.3 (D), R68.1, R76.1; also elsewhere on the board
/USB/CC1: J6.A5, R66.1
/USB/CC2: J6.B5, R75.1
GND: IC5.4 (V-), J4.1, J6.A1, J6.A12, J6.B1, J6.B12, J6.MP1, J6.MP2, J6.MP3, J6.MP4, R66.2, R75.2, R79.2, R81.2; also elsewhere on the board
unnamed: D1.1 (K), Q1.1 (G), R76.2
unnamed: IC5.1 (OUT1), R80.1, R83.2
unnamed: IC5.2 (IN1-), R77.1, R80.2
unnamed: IC5.3 (IN1+), R78.1, R79.1
unnamed: IC5.5 (IN2+), R81.1, R86.1
unnamed: IC5.6 (IN2-), R82.2, R85.1
unnamed: IC5.7 (OUT2), R82.1, R84.2
unnamed: J4.2, R88.1
unnamed: J4.3, R87.1
unnamed: Q1.2 (S), R70.1
USB_CONN_D_N: J6.A7, J6.B7, R73.1, R74.2
USB_CONN_D_P: J6.A6, J6.B6, R71.2, R72.1
USB_D_N: R71.1, R73.2, R88.2; also elsewhere on the board
USB_D_P: R72.2, R74.1, R87.2; also elsewhere on the board
USB_POWER_IN: J5.2; also elsewhere on the board
USB_POWER_IN_REC: J6.A4, J6.A9, J6.B4, J6.B9, R69.1

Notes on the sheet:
Solder header for USB cable
DUT USB PORT
Note, this side is backup
Diff to SE op amp
Note: I have these in stock

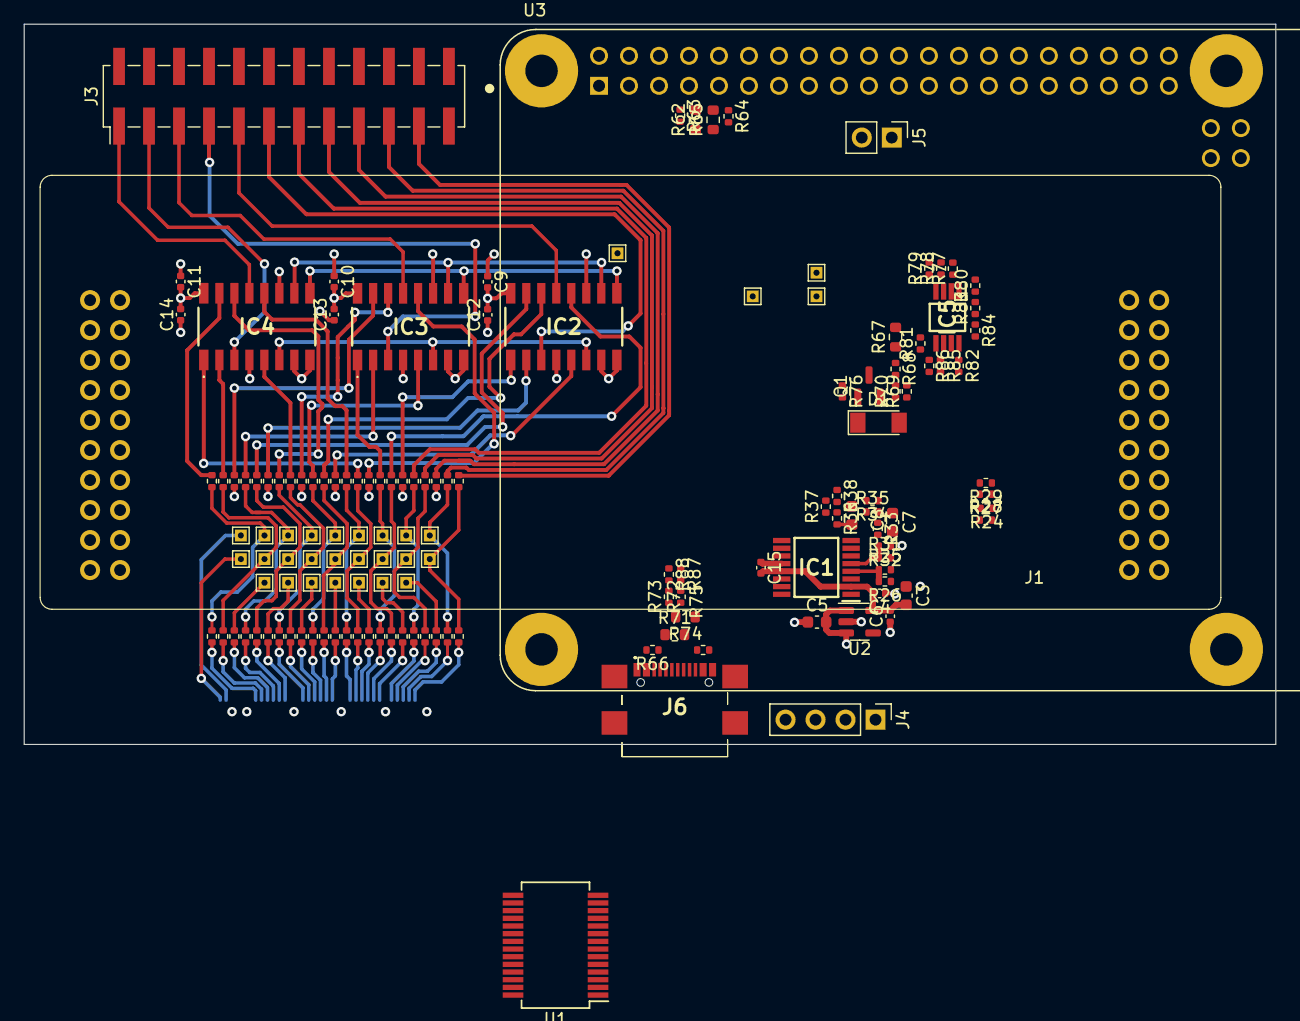
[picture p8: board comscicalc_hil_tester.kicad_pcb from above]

Board: 4 copper layers, 106.0 x 61.0 mm, 116 parts (1 on the bottom side), 141 nets.

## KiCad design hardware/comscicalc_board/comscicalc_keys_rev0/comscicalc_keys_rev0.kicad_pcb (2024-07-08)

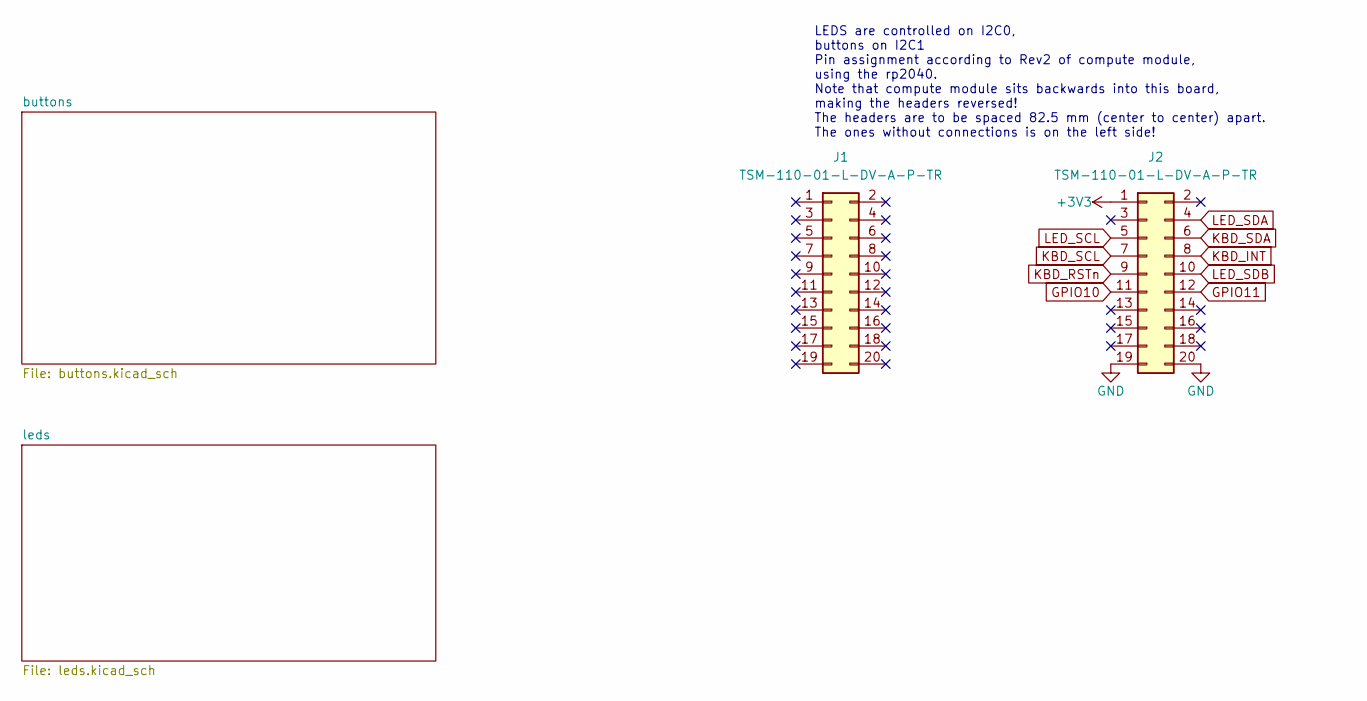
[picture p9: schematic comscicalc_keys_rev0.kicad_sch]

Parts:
J1, J2: TSM-110-01-L-DV-A-P-TR; PinSocket_2x10_P2.54mm_Vertical

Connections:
+3V3: J2.1; also elsewhere on the board
GND: J2.19, J2.20; also elsewhere on the board
GPIO10: J2.11
GPIO11: J2.12
KBD_INT: J2.8; also elsewhere on the board
KBD_RSTn: J2.9; also elsewhere on the board
KBD_SCL: J2.7; also elsewhere on the board
KBD_SDA: J2.6; also elsewhere on the board
LED_SCL: J2.5; also elsewhere on the board
LED_SDA: J2.4; also elsewhere on the board
LED_SDB: J2.10; also elsewhere on the board

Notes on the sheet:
LEDS are controlled on I2C0, buttons on I2C1 Pin assignment according to Rev2 of compute module, using the rp2040. Note that compute module sits backwards into this board, making the headers reversed! The headers are to be spaced 82.5 mm (center to center) apart. The ones without connections is on 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

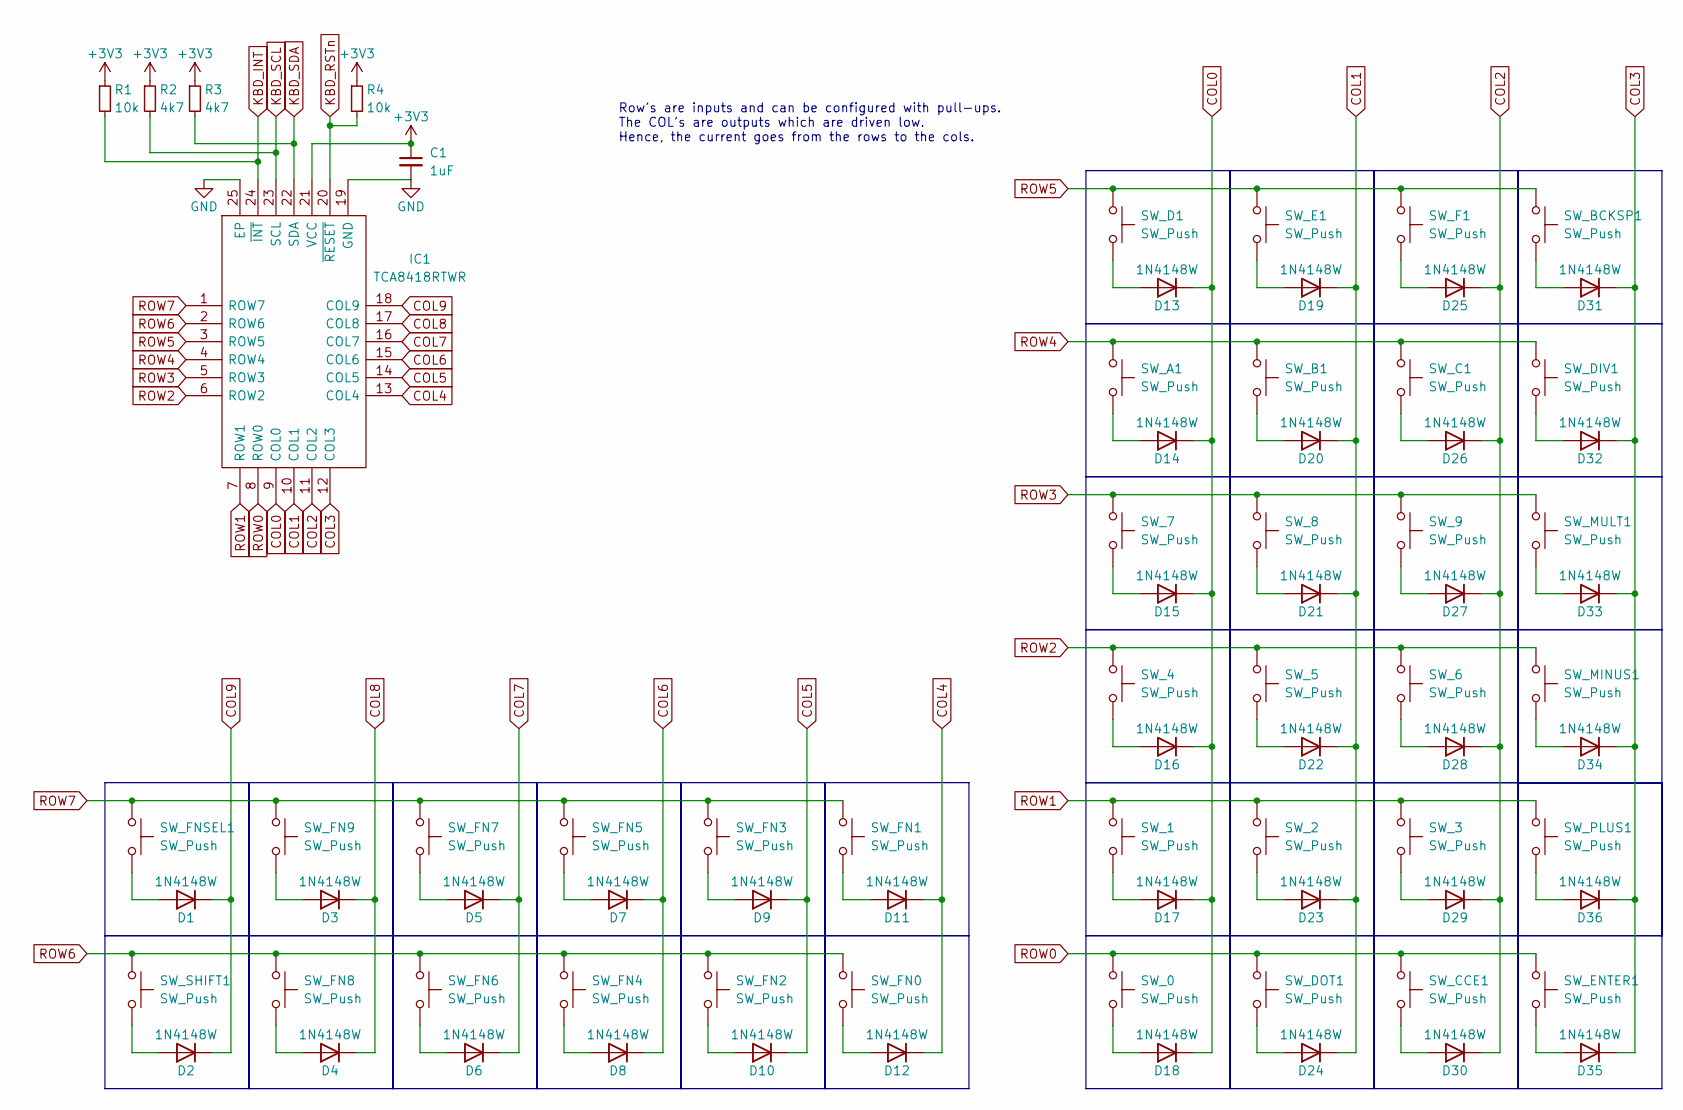
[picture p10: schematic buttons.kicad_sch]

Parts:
C1: 1uF; C_0402_1005Metric
D1, D2, D3, D4, D5, D6, D7, D8, D9, D10, D11, D12, D13, D14, D15, D16, D17, D18, D19, D20, D21, D22, D23, D24, D25, D26, D27, D28, D29, D30, D31, D32, D33, D34, D35, D36: 1N4148W; D_SOD-123
IC1: TCA8418RTWR; QFN50P400X400X80-25N; Mouser Part Number 595-TCA8418RTWR
R1, R4: 10k; R_0402_1005Metric
R2, R3: 4k7; R_0402_1005Metric
SW_0, SW_1, SW_2, SW_3, SW_4, SW_5, SW_6, SW_7, SW_8, SW_9: SW_Push; Kailh_socket_PG1350
SW_A1: SW_Push; Kailh_socket_PG1350
SW_B1: SW_Push; Kailh_socket_PG1350
SW_BCKSP1: SW_Push; Kailh_socket_PG1350
SW_C1: SW_Push; Kailh_socket_PG1350
SW_CCE1: SW_Push; Kailh_socket_PG1350
SW_D1: SW_Push; Kailh_socket_PG1350
SW_DIV1: SW_Push; Kailh_socket_PG1350
SW_DOT1: SW_Push; Kailh_socket_PG1350
SW_E1: SW_Push; Kailh_socket_PG1350
SW_ENTER1: SW_Push; Kailh_socket_PG1350
SW_F1: SW_Push; Kailh_socket_PG1350
SW_FN0, SW_FN1, SW_FN2, SW_FN3, SW_FN4, SW_FN5, SW_FN6, SW_FN7, SW_FN8, SW_FN9: SW_Push; Kailh_socket_PG1350
SW_FNSEL1: SW_Push; Kailh_socket_PG1350
SW_MINUS1: SW_Push; Kailh_socket_PG1350
SW_MULT1: SW_Push; Kailh_socket_PG1350
SW_PLUS1: SW_Push; Kailh_socket_PG1350
SW_SHIFT1: SW_Push; Kailh_socket_PG1350

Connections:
+3V3: C1.1, IC1.21 (VCC), R1.1, R2.1, R3.1, R4.1; also elsewhere on the board
COL0: D13.1 (K), D14.1 (K), D15.1 (K), D16.1 (K), D17.1 (K), D18.1 (K), IC1.9 (COL0)
COL1: D19.1 (K), D20.1 (K), D21.1 (K), D22.1 (K), D23.1 (K), D24.1 (K), IC1.10 (COL1)
COL2: D25.1 (K), D26.1 (K), D27.1 (K), D28.1 (K), D29.1 (K), D30.1 (K), IC1.11 (COL2)
COL3: D31.1 (K), D32.1 (K), D33.1 (K), D34.1 (K), D35.1 (K), D36.1 (K), IC1.12 (COL3)
COL4: D11.1 (K), D12.1 (K), IC1.13 (COL4)
COL5: D9.1 (K), D10.1 (K), IC1.14 (COL5)
COL6: D7.1 (K), D8.1 (K), IC1.15 (COL6)
COL7: D5.1 (K), D6.1 (K), IC1.16 (COL7)
COL8: D3.1 (K), D4.1 (K), IC1.17 (COL8)
COL9: D1.1 (K), D2.1 (K), IC1.18 (COL9)
GND: C1.2, IC1.19 (GND), IC1.25 (EP); also elsewhere on the board
KBD_INT: IC1.24 (~INT), R1.2; also elsewhere on the board
KBD_RSTn: IC1.20 (~RESET), R4.2; also elsewhere on the board
KBD_SCL: IC1.23 (SCL), R2.2; also elsewhere on the board
KBD_SDA: IC1.22 (SDA), R3.2; also elsewhere on the board
unnamed: D1.2 (A), SW_FNSEL1.2
unnamed: D2.2 (A), SW_SHIFT1.2
unnamed: D3.2 (A), SW_FN9.2
unnamed: D4.2 (A), SW_FN8.2
unnamed: D5.2 (A), SW_FN7.2
unnamed: D6.2 (A), SW_FN6.2
unnamed: D7.2 (A), SW_FN5.2
unnamed: D8.2 (A), SW_FN4.2
unnamed: D9.2 (A), SW_FN3.2
unnamed: D10.2 (A), SW_FN2.2
unnamed: D11.2 (A), SW_FN1.2
unnamed: D12.2 (A), SW_FN0.2
unnamed: D13.2 (A), SW_D1.2
unnamed: D14.2 (A), SW_A1.2
unnamed: D15.2 (A), SW_7.2
unnamed: D16.2 (A), SW_4.2
unnamed: D17.2 (A), SW_1.2
unnamed: D18.2 (A), SW_0.2
unnamed: D19.2 (A), SW_E1.2
unnamed: D20.2 (A), SW_B1.2
unnamed: D21.2 (A), SW_8.2
unnamed: D22.2 (A), SW_5.2
unnamed: D23.2 (A), SW_2.2
unnamed: D24.2 (A), SW_DOT1.2
unnamed: D25.2 (A), SW_F1.2
unnamed: D26.2 (A), SW_C1.2
unnamed: D27.2 (A), SW_9.2
unnamed: D28.2 (A), SW_6.2
unnamed: D29.2 (A), SW_3.2
unnamed: D30.2 (A), SW_CCE1.2
unnamed: D31.2 (A), SW_BCKSP1.2
unnamed: D32.2 (A), SW_DIV1.2
unnamed: D33.2 (A), SW_MULT1.2
unnamed: D34.2 (A), SW_MINUS1.2
unnamed: D35.2 (A), SW_ENTER1.2
unnamed: D36.2 (A), SW_PLUS1.2
ROW0: IC1.8 (ROW0), SW_0.1, SW_CCE1.1, SW_DOT1.1, SW_ENTER1.1
ROW1: IC1.7 (ROW1), SW_1.1, SW_2.1, SW_3.1, SW_PLUS1.1
ROW2: IC1.6 (ROW2), SW_4.1, SW_5.1, SW_6.1, SW_MINUS1.1
ROW3: IC1.5 (ROW3), SW_7.1, SW_8.1, SW_9.1, SW_MULT1.1
ROW4: IC1.4 (ROW4), SW_A1.1, SW_B1.1, SW_C1.1, SW_DIV1.1
ROW5: IC1.3 (ROW5), SW_BCKSP1.1, SW_D1.1, SW_E1.1, SW_F1.1
ROW6: IC1.2 (ROW6), SW_FN0.1, SW_FN2.1, SW_FN4.1, SW_FN6.1, SW_FN8.1, SW_SHIFT1.1
ROW7: IC1.1 (ROW7), SW_FN1.1, SW_FN3.1, SW_FN5.1, SW_FN7.1, SW_FN9.1, SW_FNSEL1.1

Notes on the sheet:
Row's are inputs and can be configured with pull-ups. The COL's are outputs which are driven low. Hence, the current goes from the rows to the cols.

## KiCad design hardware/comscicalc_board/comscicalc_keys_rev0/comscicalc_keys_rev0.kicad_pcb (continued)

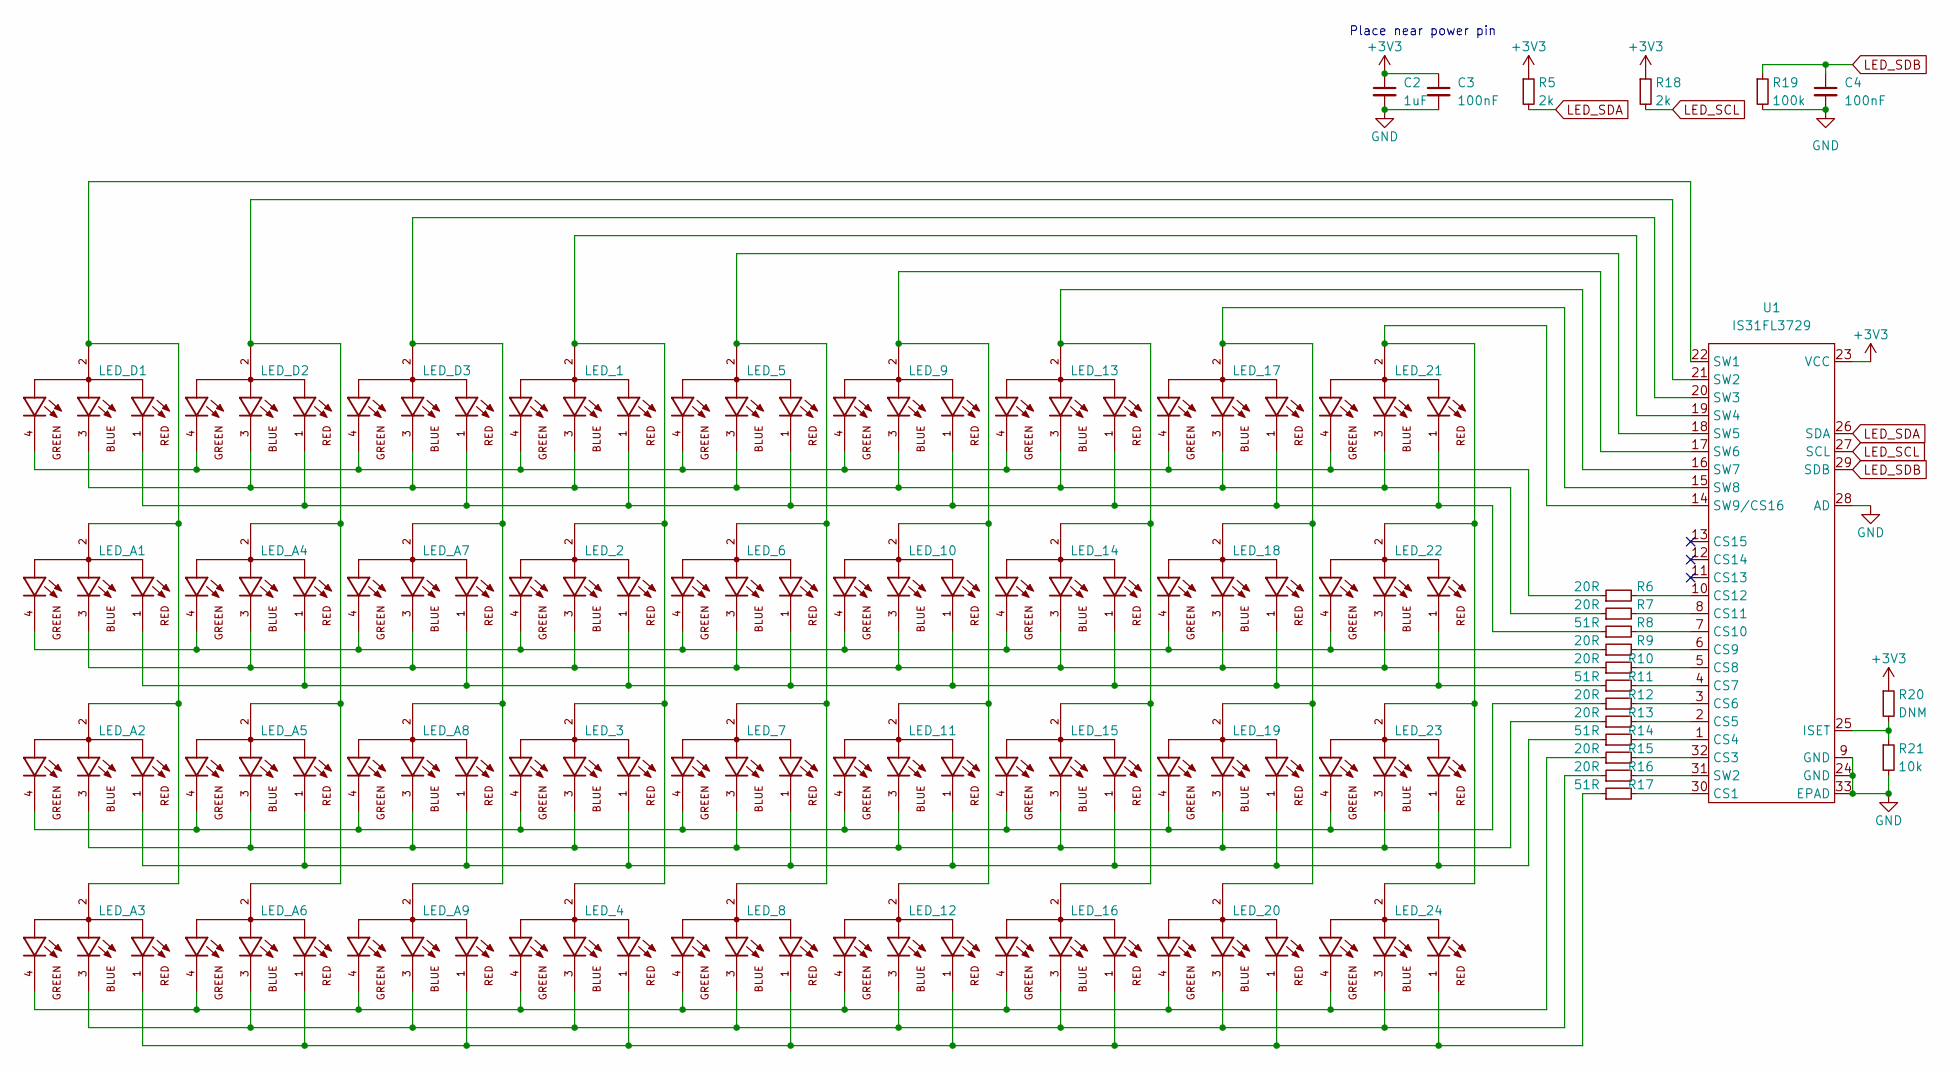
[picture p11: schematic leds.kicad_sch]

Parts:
C2: 1uF; C_0402_1005Metric
C3, C4: 100nF; C_0402_1005Metric
LED_1, LED_2, LED_3, LED_4, LED_5, LED_6, LED_7, LED_8, LED_9, LED_10, LED_11, LED_12, LED_13, LED_14, LED_15, LED_16, LED_17, LED_18, LED_19, LED_20, LED_21, LED_22, LED_23, LED_24: T36K3BGR-05D000121U1930; LED_T36K3BGR-05D000121U1930; PARTREV 1.1
LED_A1, LED_A2, LED_A3, LED_A4, LED_A5, LED_A6, LED_A7, LED_A8, LED_A9: T36K3BGR-05D000121U1930; LED_T36K3BGR-05D000121U1930; PARTREV 1.1
LED_D1, LED_D2, LED_D3: T36K3BGR-05D000121U1930; LED_T36K3BGR-05D000121U1930; PARTREV 1.1
R5, R18: 2k; R_0402_1005Metric
R6, R7, R9, R10, R12, R13, R15, R16: 20R; R_0402_1005Metric
R8, R11, R14, R17: 51R; R_0402_1005Metric
R19: 100k; R_0402_1005Metric
R20: DNM; R_0402_1005Metric
R21: 10k; R_0402_1005Metric
U1: IS31FL3729; IS31FL3729_QFN32

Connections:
+3V3: C2.1, C3.1, R5.1, R18.1, R20.1, U1.23 (VCC); also elsewhere on the board
GND: C2.2, C3.2, C4.2, R19.2, R21.2, U1.9 (GND), U1.24 (GND), U1.28 (AD), U1.33 (EPAD); also elsewhere on the board
LED_SCL: R18.2, U1.27 (SCL); also elsewhere on the board
LED_SDA: R5.2, U1.26 (SDA); also elsewhere on the board
LED_SDB: C4.1, R19.1, U1.29 (SDB); also elsewhere on the board
unnamed: LED_1.1, LED_5.1, LED_9.1, LED_13.1, LED_17.1, LED_21.1, LED_D1.1, LED_D2.1, LED_D3.1, R8.1
unnamed: LED_1.2, LED_2.2, LED_3.2, LED_4.2, U1.19 (SW4)
unnamed: LED_1.3, LED_5.3, LED_9.3, LED_13.3, LED_17.3, LED_21.3, LED_D1.3, LED_D2.3, LED_D3.3, R7.1
unnamed: LED_1.4, LED_5.4, LED_9.4, LED_13.4, LED_17.4, LED_21.4, LED_D1.4, LED_D2.4, LED_D3.4, R6.1
unnamed: LED_5.2, LED_6.2, LED_7.2, LED_8.2, U1.18 (SW5)
unnamed: LED_2.1, LED_6.1, LED_10.1, LED_14.1, LED_18.1, LED_22.1, LED_A1.1, LED_A4.1, LED_A7.1, R11.1
unnamed: LED_9.2, LED_10.2, LED_11.2, LED_12.2, U1.17 (SW6)
unnamed: LED_2.3, LED_6.3, LED_10.3, LED_14.3, LED_18.3, LED_22.3, LED_A1.3, LED_A4.3, LED_A7.3, R10.1
unnamed: LED_2.4, LED_6.4, LED_10.4, LED_14.4, LED_18.4, LED_22.4, LED_A1.4, LED_A4.4, LED_A7.4, R9.1
unnamed: LED_3.1, LED_7.1, LED_11.1, LED_15.1, LED_19.1, LED_23.1, LED_A2.1, LED_A5.1, LED_A8.1, R14.1
unnamed: LED_3.3, LED_7.3, LED_11.3, LED_15.3, LED_19.3, LED_23.3, LED_A2.3, LED_A5.3, LED_A8.3, R13.1
unnamed: LED_3.4, LED_7.4, LED_11.4, LED_15.4, LED_19.4, LED_23.4, LED_A2.4, LED_A5.4, LED_A8.4, R12.1
unnamed: LED_4.1, LED_8.1, LED_12.1, LED_16.1, LED_20.1, LED_24.1, LED_A3.1, LED_A6.1, LED_A9.1, R17.1
unnamed: LED_4.3, LED_8.3, LED_12.3, LED_16.3, LED_20.3, LED_24.3, LED_A3.3, LED_A6.3, LED_A9.3, R16.1
unnamed: LED_4.4, LED_8.4, LED_12.4, LED_16.4, LED_20.4, LED_24.4, LED_A3.4, LED_A6.4, LED_A9.4, R15.1
unnamed: LED_13.2, LED_14.2, LED_15.2, LED_16.2, U1.16 (SW7)
unnamed: LED_17.2, LED_18.2, LED_19.2, LED_20.2, U1.15 (SW8)
unnamed: LED_21.2, LED_22.2, LED_23.2, LED_24.2, U1.14 (SW9/CS16)
unnamed: LED_A1.2, LED_A2.2, LED_A3.2, LED_D1.2, U1.22 (SW1)
unnamed: LED_A4.2, LED_A5.2, LED_A6.2, LED_D2.2, U1.21 (SW2)
unnamed: LED_A7.2, LED_A8.2, LED_A9.2, LED_D3.2, U1.20 (SW3)
unnamed: R6.2, U1.10 (CS12)
unnamed: R7.2, U1.8 (CS11)
unnamed: R8.2, U1.7 (CS10)
unnamed: R9.2, U1.6 (CS9)
unnamed: R10.2, U1.5 (CS8)
unnamed: R11.2, U1.4 (CS7)
unnamed: R12.2, U1.3 (CS6)
unnamed: R13.2, U1.2 (CS5)
unnamed: R14.2, U1.1 (CS4)
unnamed: R15.2, U1.32 (CS3)
unnamed: R16.2, U1.31 (SW2)
unnamed: R17.2, U1.30 (CS1)
unnamed: R20.2, R21.1, U1.25 (ISET)

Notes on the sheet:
Place near power pin

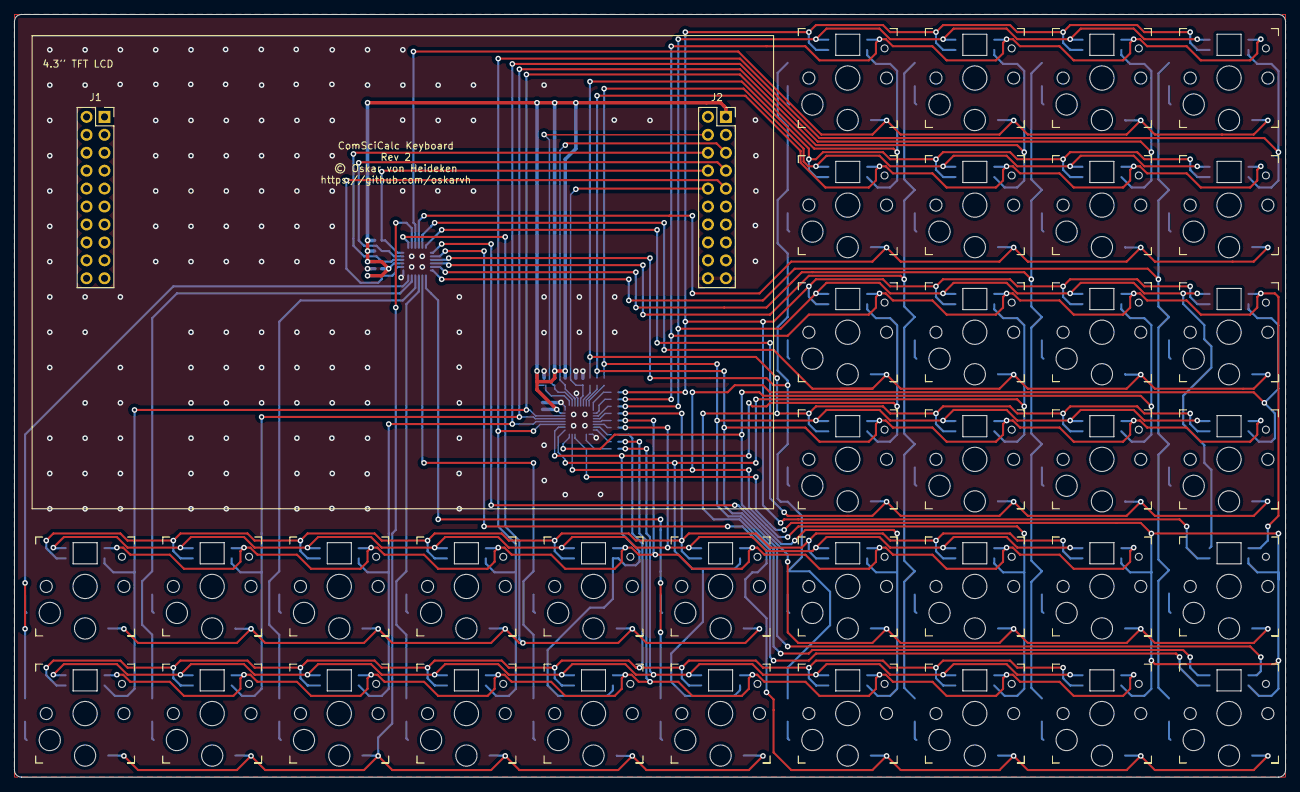
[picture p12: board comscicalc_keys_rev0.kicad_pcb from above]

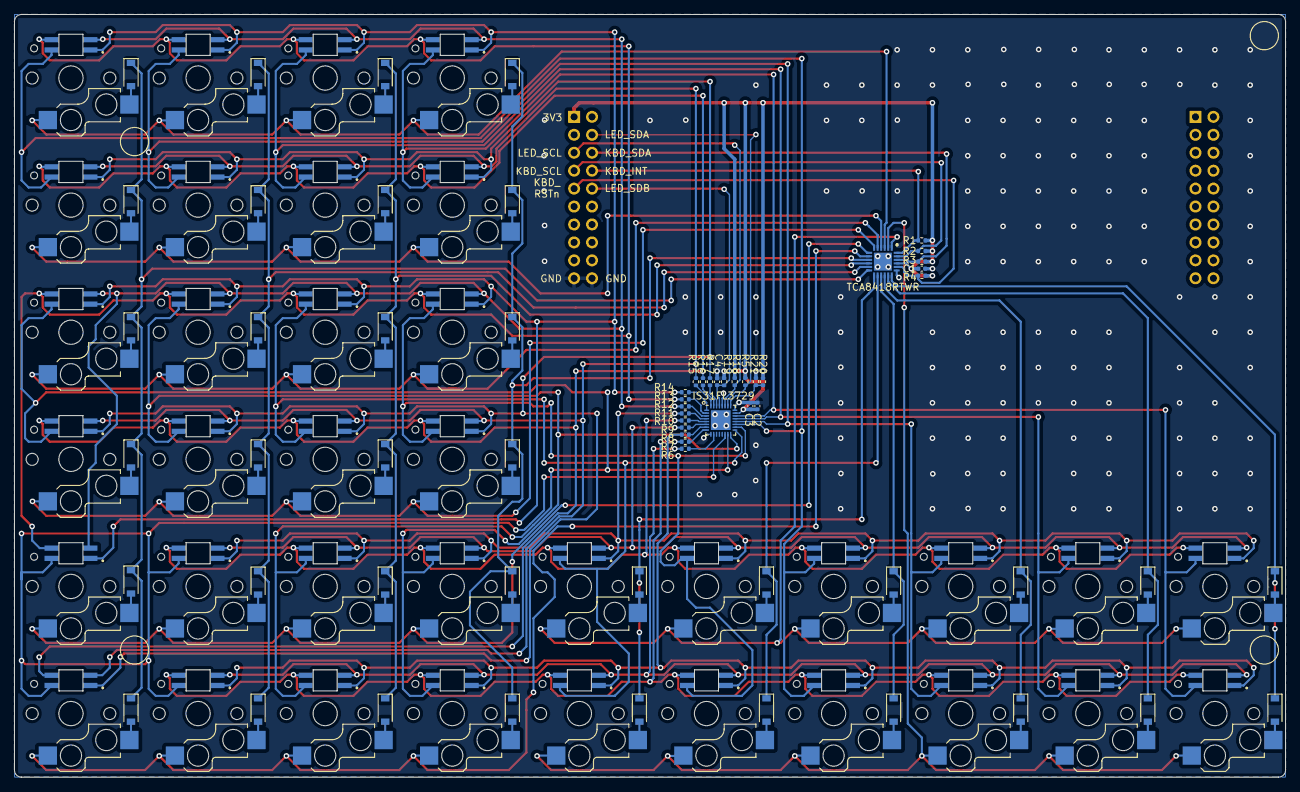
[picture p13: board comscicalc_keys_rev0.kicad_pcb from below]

Board: 2 copper layers, 180.0 x 108.0 mm, 137 parts (99 on the bottom side), 97 nets.

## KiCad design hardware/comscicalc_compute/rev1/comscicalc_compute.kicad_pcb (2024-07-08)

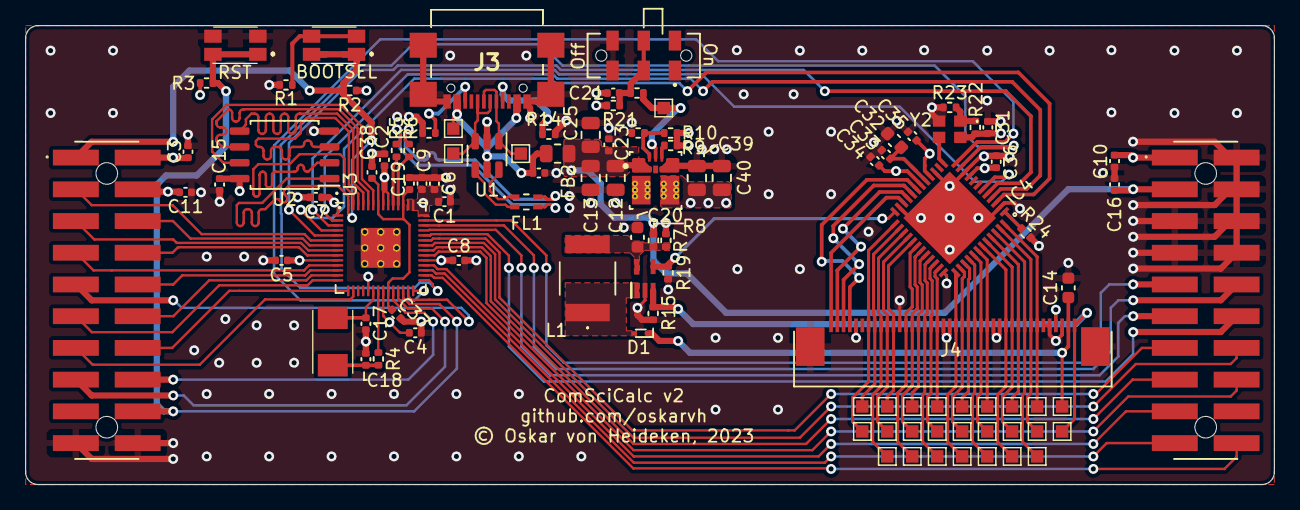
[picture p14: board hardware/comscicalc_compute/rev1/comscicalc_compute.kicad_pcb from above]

Board: 4 copper layers, 100.0 x 36.8 mm, 102 parts (0 on the bottom side), 96 nets.

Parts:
C1, C2, C4, C5, C6, C7, C8, C15, C21, C23, C31, C33, C34, C35, C36, C37, C38: 100nF; C_0402_1005Metric
C3, C9, C10, C11, C16, C19: 1uF; C_0402_1005Metric
C12, C25: 10uF; C_0805_2012Metric
C13, C39, C40: 22uF; C_0805_2012Metric
C14: 1uF; C_0603_1608Metric
C17, C18: 27pF; C_0402_1005Metric
C20, C32: 4.7uF; C_0603_1608Metric
C22: 10nF; C_0402_1005Metric
D1: NSR0240P2T5G; SODFL1006X40N
FB2: BLM21PG300SN1D; R_0805_2012Metric
FL1: ACM2012-361-2P-T002; ACM20121022PT001
IC2: TPS92360DCKR; SOT65P210X110-5N
IC4: FT811Q-T; QFN50P700X700X90-49N-D
J1, J2: TSM-110-01-L-DV-A-P-TR; TSM-110-YY-ZZZ-DV-A-P-TR
J3: USB4110-GF-A; USB4110GFA
J4: 4-1734839-0
L1: ASPI-0403S-1R5M-T; ASPI0403S332MT
R1, R4, R19, R20: 1k; R_0402_1005Metric
R2, R3, R9, R21, R24: 10k; R_0402_1005Metric
R5, R6: 27R; R_0402_1005Metric
R7, R10, R22: 0R; R_0402_1005Metric
R8, R11, R23: DNM; R_0402_1005Metric
R14, R18: 5.1k; R_0402_1005Metric
R15: 22R; R_0402_1005Metric
S1, S2: EVQ-P7J01P; EVQP7J01P
SW2: JS202011JAQN
TB_PCLK1: TestPoint_Small; TestPoint_Pad_1.0x1.0mm
TP1: TestPoint; TestPoint_Pad_1.0x1.0mm
TPB2, TPB3, TPB4, TPB5, TPB6, TPB7: TestPoint_Small; TestPoint_Pad_1.0x1.0mm
TPDR1, TPDR2, TPDR3: TestPoint_Small; TestPoint_Pad_1.0x1.0mm
TPG2, TPG3, TPG4, TPG5, TPG6, TPG7: TestPoint_Small; TestPoint_Pad_1.0x1.0mm
TPR1, TPR2, TPR3, TPR4, TPR5, TPR6, TPR7, TPR8: TestPoint_Small; TestPoint_Pad_1.0x1.0mm
TP_DE1: TestPoint_Small; TestPoint_Pad_1.0x1.0mm
TP_DISP1: TestPoint_Small; TestPoint_Pad_1.0x1.0mm
TP_HSYNC1: TestPoint_Small; TestPoint_Pad_1.0x1.0mm
TP_VSYNC1: TestPoint_Small; TestPoint_Pad_1.0x1.0mm
U1: USBLC6-2SC6; SOT-23-6
U2: W25Q32JVSSIQ; SOIC-8_5.23x5.23mm_P1.27mm
U3: RP2040; RP2040-QFN-56
U4: TPSM863253; RDX0007A-MFG
Y1: 445I23D12M00000; 445I23D24M00000
Y2: ECS-2520MV-120-BN-TR; X1G004171001800

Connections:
+3V3: C1.1, C2.1, C3.1, C4.1, C5.1, C6.1, C7.1, C8.1, C9.1, C10.1, C15.1, C31.1, C34.1, C35.1, C36.1, C39.1, C40.1, IC4.9 (VCCIO1), IC4.16 (VCC_1), IC4.18 (VCC_2), J1.2, J2.1, J4.37, R2.1, R3.1, R7.2, R9.2, R10.2, R22.2, U2.8 (VCC), U3.1 (IOVDD), U3.10 (IOVDD), U3.22 (IOVDD), U3.33 (IOVDD), U3.42 (IOVDD), U3.43 (ADC_AVDD), U3.44 (VREG_IN), U3.48 (USB_VDD), U3.49 (IOVDD), U4.3 (VOUT), Y2.4 (VCC)
+5V: C11.1, C12.1, C13.1, C16.1, C23.1, C25.1, FB2.2, J1.4, J2.3, R8.2, R21.1, U4.1 (VIN)
/LCD/B2: IC4.35 (B2), J4.18, TPB2.1
/LCD/B3: IC4.34 (B3), J4.17, TPB3.1
/LCD/B4: IC4.33 (B4), J4.16, TPB4.1
/LCD/B5: IC4.32 (B5), J4.15, TPB5.1
/LCD/B6: IC4.31 (B6), J4.14, TPB6.1
/LCD/B7: IC4.30 (B7), J4.13, TPB7.1
/LCD/DE: IC4.25 (DE), J4.7, TP_DE1.1
/LCD/DISP: IC4.28 (DISP), J4.10, TP_DISP1.1
/LCD/FT_1V2: C32.1, C33.1, IC4.17 (VOUT1V2)
/LCD/FT_XOSC: IC4.13 (X1/CLK), Y2.3 (OUT)
/LCD/G2: IC4.42 (G2), J4.26, TPG2.1
/LCD/G3: IC4.41 (G3), J4.25, TPG3.1
/LCD/G4: IC4.40 (G4), J4.24, TPG4.1
/LCD/G5: IC4.39 (G5), J4.23, TPG5.1
/LCD/G6: IC4.38 (G6), J4.22, TPG6.1
/LCD/G7: IC4.37 (G7), J4.21, TPG7.1
/LCD/HSYNC: IC4.27 (HSYNC), J4.9, TP_HSYNC1.1
/LCD/PCLK: IC4.29 (PCLK), J4.11, TB_PCLK1.1
/LCD/R2: IC4.48 (R2), J4.34, TPR2.1
/LCD/R3: IC4.47 (R3), J4.33, TPR3.1
/LCD/R4: IC4.46 (R4), J4.32, TPR4.1
/LCD/R5: IC4.45 (R5), J4.31, TPR5.1
/LCD/R6: IC4.44 (R6), J4.30, TPR6.1
/LCD/R7: IC4.43 (R7), J4.29, TPR7.1
/LCD/VSYNC: IC4.26 (VSYNC), J4.8, TP_VSYNC1.1
/LCD/X+: IC4.19 (XP), J4.4
/LCD/X-: IC4.21 (XM), J4.2
/LCD/Y+: IC4.20 (YP), J4.3
/LCD/Y-: IC4.22 (YM), J4.1
/MCU/QSPI_CSn: J1.1, R2.2, S2.1, S2.2 (1'), U2.1 (~CS), U3.56 (QSPI_SS)
/MCU/QSPI_SCLK: U2.6 (CLK), U3.52 (QSPI_SCLK)
/MCU/QSPI_SD0: U2.5 (DI(IO0)), U3.53 (QSPI_SD0)
/MCU/QSPI_SD1: U2.2 (DO(IO1)), U3.55 (QSPI_SD1)
/MCU/QSPI_SD2: U2.3 (IO2), U3.54 (QSPI_SD2)
/MCU/QSPI_SD3: U2.7 (IO3), U3.51 (QSPI_SD3)
/MCU/RSTn/RUN: J1.18, R3.2, S1.1, S1.2 (1'), U3.26 (RUN)
/MCU/SWCLK: J1.16, U3.24 (SWCLK)
/MCU/SWD: J1.15, U3.25 (SWD)
/MCU/USB_RP_N: R6.1, U3.46 (USB_DM)
/MCU/USB_RP_P: R5.1, U3.47 (USB_DP)
/MCU/XIN: C17.2, U3.20 (XIN), Y1.2
/MCU/XOUT: R4.2, U3.21 (XOUT)
/POWER/24V_IN: C20.1, IC2.5 (VIN), L1.2, R7.1, R8.1
/POWER/24V_SW: D1.2, IC2.1 (SW), L1.1
/POWER/CC1: J3.A5, R14.1
/POWER/CC2: J3.B5, R18.1
/POWER/PWR_EN: R20.2, TP1.1, U4.6 (EN)
/POWER/USB_EMI_D_N: FL1.2, U1.4 (I/O2)
/POWER/USB_EMI_D_P: FL1.1, U1.6 (I/O1)
BACKLIGHT_DRIVE: C14.1, D1.1, J4.39, TPDR1.1
BACKLIGHT_FB: IC2.3 (FB), J4.40, R15.1, TPDR2.1
BACKLIGHT_PWM: IC2.4 (CTRL), IC4.24 (BACKLIGHT), R19.1
FT811_INTN: IC4.11 (INT_N), U3.29 (GPIO18)
FT811_PDN: IC4.12 (PD_N), U3.28 (GPIO17)
GND: C1.2, C2.2, C3.2, C4.2, C5.2, C6.2, C7.2, C8.2, C9.2, C10.2, C11.2, C12.2, C13.2, C14.2, C15.2, C16.2, C17.1, C18.1, C19.2, C20.2, C21.2, C22.2, C23.2, C25.2, C31.2, C32.2, C33.2, C34.2, C35.2, C36.2, C37.2, C38.2, C39.2, C40.2, IC2.2 (GND), IC4.2 (GND_1), IC4.10 (GPIO2), IC4.15 (GND_2), IC4.23 (GND_3), IC4.36 (GND_4), IC4.49 (EP), J1.19, J1.20, J2.2, J2.4, J2.5, J2.6, J2.7, J2.8, J3.A1, J3.A12, J3.B1, J3.B12, J3.MP1, J3.MP2, J3.MP3, J3.MP4, J4.5, J4.12, J4.19, J4.20, J4.27, J4.28, J4.35, J4.36, J4.38, J4.41 (EP), J4.42 (EP), R1.2, R11.1, R14.2, R15.2, R18.2, R19.2, R23.1, R24.2, S1.3 (2), S1.4 (2'), SW2.3, SW2.7, U1.2 (GND), U2.4 (GND), U3.19 (TESTEN), U3.57 (GND), U4.4 (PGND), Y2.2 (GND)
GPIO10: J1.12, U3.13 (GPIO10)
GPIO11: J1.11, U3.14 (GPIO11)
GPIO19: J2.20, U3.30 (GPIO19)
GPIO20: J2.19, U3.31 (GPIO20)
GPIO21: J2.17, U3.32 (GPIO21)
GPIO22: J2.16, U3.34 (GPIO22)
GPIO23: J2.15, U3.35 (GPIO23)
GPIO24: J2.14, U3.36 (GPIO24)
GPIO25: J2.13, U3.37 (GPIO25)
GPIO26: J2.12, U3.38 (GPIO26_ADC0)
GPIO27: J2.11, U3.39 (GPIO27_ADC1)
GPIO28: J2.10, U3.40 (GPIO28_ADC2)
GPIO29: J2.9, U3.41 (GPIO29_ADC3)
KBD_INTn: J1.7, U3.11 (GPIO8)
KBD_RST: J1.10, U3.12 (GPIO9)
LED_SDBn: J1.9, U3.27 (GPIO16)
unnamed: C18.2, R4.1, Y1.1
unnamed: C19.1, C37.1, C38.1, U3.23 (DVDD), U3.45 (VREG_VOUT), U3.50 (DVDD)
unnamed: C21.1, R20.1, R21.2, SW2.2, SW2.6
unnamed: IC4.1 (AUDIO_L), R24.1
unnamed: R1.1, S2.3 (2), S2.4 (2')
unnamed: R9.1, U4.5 (PG)
unnamed: R10.1, R11.2, U4.7 (FB)
unnamed: R22.1, R23.2, Y2.1 (~ST)
SCL0_LED: J1.6, U3.7 (GPIO5)
SCL1_KBD: J1.8, U3.9 (GPIO7)
SDA0_LED: J1.3, U3.6 (GPIO4)
SDA1_KBD: J1.5, U3.8 (GPIO6)
SPI0_CSn: IC4.6 (CS_N), U3.3 (GPIO1)
SPI0_MISO: IC4.4 (MISO/IO1), U3.2 (GPIO0)
SPI0_MOSI: IC4.5 (MOSI/IO0), U3.5 (GPIO3)
SPI0_SCK: IC4.3 (SCK), U3.4 (GPIO2)
UART0_RX: J1.13, U3.16 (GPIO13)
UART0_TX: J1.14, U3.15 (GPIO12)
USB_CONN_D_N: J3.A7, J3.B7, TPR8.1, U1.1 (I/O1)
USB_CONN_D_P: J3.A6, J3.B6, TPR1.1, U1.3 (I/O2)
USB_D_N: FL1.4, R6.2
USB_D_P: FL1.3, R5.2
USB_POWER_IN: C22.1, FB2.1, J3.A4, J3.A9, J3.B4, J3.B9, TPDR3.1, U1.5 (VBUS)

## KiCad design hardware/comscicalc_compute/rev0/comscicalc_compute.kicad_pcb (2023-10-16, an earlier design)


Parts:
C1, C7: 22pF; C_0402_1005Metric; LCSC C1555
C2, C3, C4, C5, C6, C8, C9, C10: 100nF; C_0402_1005Metric; LCSC C1525
IC1: R7FA4M3AF3CFM#AA0; QFP50P1200X1200X170-64N; Mouser Part Number 968-R7FA4M3AF3CFMAA0
J1, J2: Conn_02x14_Odd_Even; PinHeader_2x14_P2.54mm_Vertical_SMD; LCSC DNM
R1, R2, R9, R10, R11, R12, R13, R50: DNM; R_0402_1005Metric; LCSC DNM
R3, R7: 0R; R_0402_1005Metric; LCSC C174180
R4, R6, R8, R49: 10k; R_0402_1005Metric; LCSC C140214
R5: 1k; R_0402_1005Metric; LCSC C279981
SW1: SSSS211603; LCSC C125040
Y1: FL2400022; Mouser Part Number 729-FL2400022

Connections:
+3V3: C2.1, C3.1, C4.1, C5.1, C6.1, C8.1, IC1.11 (VCC_1), IC1.20 (VCC_USB), IC1.39 (VCC_2), IC1.50 (VCC_3), IC1.55 (VREFH), IC1.56 (AVCC0), IC1.59 (VREFH0), J1.1, J1.27, J1.28, J2.1, J2.3, R4.1, R6.1, R49.1; also elsewhere on the board
/MCU/EXTAL: C1.1, IC1.10 (P212/EXTAL), R1.1, Y1.1 (XTAL_1)
/MCU/MD: IC1.26 (P201/MD), R2.2, SW1.2 (B)
/MCU/SWCLK/TCK: IC1.32 (P300/TCK/SWCLK), R3.1
/MCU/SWDIO/TMS: IC1.33 (P108/TMS/SWDIO), J1.2, R13.1
/MCU/SWO/TDO/TXD9: IC1.34 (P109/TDO/SWO), J1.6, R12.1
/MCU/TDI/RXD9: IC1.35 (P110/TDI), J1.8, R11.1
/MCU/VCL: C10.1, IC1.41 (VCL)
/MCU/VCL0: C9.1, IC1.5 (VCL0)
/MCU/XTAL: IC1.9 (P213/XTAL), R1.2, R7.1
/MCU/nRESET: IC1.25 (RES), J1.10, R6.2
BACKLIGHT_PWM: R9.1; also elsewhere on the board
FT811_INTN: IC1.2 (P401); also elsewhere on the board
FT811_PDN: IC1.3 (P402); also elsewhere on the board
GND: C1.2, C2.2, C3.2, C4.2, C5.2, C6.2, C7.2, C8.2, C9.2, C10.2, IC1.4 (VBATT), IC1.8 (VSS_1), IC1.17 (VSS_USB), IC1.40 (VSS_2), IC1.51 (VSS_3), IC1.54 (VREFL), IC1.57 (AVSS0), IC1.58 (VREFL0), J1.3, J1.5, J1.9, J1.15, J1.16, J1.17, J1.18, J1.19, J2.5, J2.6, J2.7, J2.8, J2.24, J2.25, J2.26, J2.27, J2.28, R5.2, R8.1, Y1.2 (CASE_1), Y1.4 (CASE_2); also elsewhere on the board
KBD_INTn: IC1.28 (P304), J1.26
KBD_RST: IC1.29 (P303), J1.24
LED_SDBn: IC1.13 (P410), J1.21
NMI: IC1.27 (P200), J1.14
unnamed: C7.1, R7.2, Y1.3 (XTAL_2)
unnamed: IC1.1 (P400), R9.2
unnamed: IC1.6 (XCIN), R8.2
unnamed: IC1.36 (P111), R10.1
unnamed: J1.4, R2.1, R3.2
unnamed: R4.2, SW1.3 (C)
unnamed: R5.1, SW1.1 (A)
P000: IC1.64 (P000), J2.9
P001: IC1.63 (P001), J2.10
P002: IC1.62 (P002), J2.11
P003: IC1.61 (P003), J2.12
P004: IC1.60 (P004), J2.13
P014: IC1.53 (P014), J2.14
P015: IC1.52 (P015), J2.15
P104: IC1.44 (P104)
P105: IC1.43 (P105)
P112: IC1.37 (P112), J2.22
P113: IC1.38 (P113), J2.23
P205: IC1.23 (P205), J2.20
P206: IC1.22 (P206), J2.19
P207: IC1.21 (P207), J2.18
P208: IC1.24 (P208), J2.21
P411: IC1.12 (P411), J2.16
SCI_MISO_0: IC1.48 (P100), R11.2; also elsewhere on the board
SCI_MOSI_0: IC1.47 (P101), R12.2; also elsewhere on the board
SCI_SCK_0: IC1.46 (P102), R10.2; also elsewhere on the board
SCI_SCL2_KBD: IC1.31 (P301), J1.20
SCI_SCL3_LED: IC1.15 (P408), J1.23
SCI_SDA2_KBD: IC1.30 (P302), J1.22
SCI_SDA3_LED: IC1.14 (P409), J1.25
SCI_SS_0: IC1.45 (P103), R13.2; also elsewhere on the board
USB_D_N: IC1.18 (USB_DM); also elsewhere on the board
USB_D_P: IC1.19 (USB_DP); also elsewhere on the board
USB_POWER: J2.2, J2.4, R50.1; also elsewhere on the board
USB_VBUS: IC1.16 (P407), R49.2, R50.2

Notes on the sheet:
SERIAL/GPIO
Clock
DECOUPLING
It's a bit strange that HW SPI shares the JTAG pins
These go to the keyboard controller
These go to the LCD controller
MD=1 gives single-chip mode MD=0 gives USB/SCI boot mode
Place near VCC
VBATT not used
Trace is not supported on this device
Boot switch
MCU
VBATT SHOULD NOT BE GND!
These go to the LED controller
JTAG/SWI/GPIO


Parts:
C31, C33, C34, C35, C36: 100nF; C_0402_1005Metric; LCSC C1525
C32: 4.7uF; C_0603_1608Metric; LCSC C19666
IC4: FT811Q-T; QFN50P700X700X90-49N-D; Mouser Part Number 895-FT811Q-T
J4: 4-1734839-0; Mouser Part Number 571-4-1734839-0
R22, R37: 0R; R_0402_1005Metric; LCSC C279984
R23: DNM; R_0402_1005Metric; LCSC DNM
R24: 10k; R_0402_1005Metric; LCSC C25086
R25, R26, R27, R28, R29, R30, R31, R32, R33, R34, R35, R36, R38, R39, R40, R41, R42, R43, R44, R45, R46, R47, R48: 33R; R_0402_1005Metric; LCSC C25105
TP8: TestPoint; TestPoint_Pad_D1.5mm
Y2: X1G004171001800; Manufacturer_Part_Number X1G004171001800; LCSC C255991

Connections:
+3V3: C31.1, C34.1, C35.1, C36.1, IC4.9 (VCCIO1), IC4.16 (VCC_1), IC4.18 (VCC_2), J4.37, R22.2, Y2.4 (VCC); also elsewhere on the board
/LCD/B2: J4.18, R38.1
/LCD/B3: J4.17, R39.1
/LCD/B4: J4.16, R40.1
/LCD/B5: J4.15, R41.1
/LCD/B6: J4.14, R42.1
/LCD/B7: J4.13, R43.1
/LCD/DE: J4.7, R48.1
/LCD/DISP: J4.10, R45.1
/LCD/FT_1V2: C32.1, C33.1, IC4.17 (VOUT1V2)
/LCD/FT_XOSC: IC4.13 (X1/CLK), TP8.1, Y2.3 (OUT)
/LCD/G2: J4.26, R31.1
/LCD/G3: J4.25, R32.1
/LCD/G4: J4.24, R33.1
/LCD/G5: J4.23, R34.1
/LCD/G6: J4.22, R35.1
/LCD/G7: J4.21, R36.1
/LCD/HSYNC: J4.9, R46.1
/LCD/PCLK: J4.11, R44.1
/LCD/R2: J4.34, R25.1
/LCD/R3: J4.33, R26.1
/LCD/R4: J4.32, R27.1
/LCD/R5: J4.31, R28.1
/LCD/R6: J4.30, R29.1
/LCD/R7: J4.29, R30.1
/LCD/VSYNC: J4.8, R47.1
/LCD/X+: IC4.19 (XP), J4.4
/LCD/X-: IC4.21 (XM), J4.2
/LCD/Y+: IC4.20 (YP), J4.3
/LCD/Y-: IC4.22 (YM), J4.1
BACKLIGHT_DRIVE: J4.39; also elsewhere on the board
BACKLIGHT_FB: J4.40; also elsewhere on the board
BACKLIGHT_PWM: R37.2; also elsewhere on the board
FT811_INTN: IC4.11 (INT_N); also elsewhere on the board
FT811_PDN: IC4.12 (PD_N); also elsewhere on the board
GND: C31.2, C32.2, C33.2, C34.2, C35.2, C36.2, IC4.2 (GND_1), IC4.10 (GPIO2), IC4.15 (GND_2), IC4.23 (GND_3), IC4.36 (GND_4), IC4.49 (EP), J4.5, J4.12, J4.19, J4.20, J4.27, J4.28, J4.35, J4.36, J4.38, J4.41 (EP), J4.42 (EP), R23.1, R24.2, Y2.2 (GND); also elsewhere on the board
unnamed: IC4.1 (AUDIO_L), R24.1
unnamed: IC4.24 (BACKLIGHT), R37.1
unnamed: IC4.25 (DE), R48.2
unnamed: IC4.26 (VSYNC), R47.2
unnamed: IC4.27 (HSYNC), R46.2
unnamed: IC4.28 (DISP), R45.2
unnamed: IC4.29 (PCLK), R44.2
unnamed: IC4.30 (B7), R43.2
unnamed: IC4.31 (B6), R42.2
unnamed: IC4.32 (B5), R41.2
unnamed: IC4.33 (B4), R40.2
unnamed: IC4.34 (B3), R39.2
unnamed: IC4.35 (B2), R38.2
unnamed: IC4.37 (G7), R36.2
unnamed: IC4.38 (G6), R35.2
unnamed: IC4.39 (G5), R34.2
unnamed: IC4.40 (G4), R33.2
unnamed: IC4.41 (G3), R32.2
unnamed: IC4.42 (G2), R31.2
unnamed: IC4.43 (R7), R30.2
unnamed: IC4.44 (R6), R29.2
unnamed: IC4.45 (R5), R28.2
unnamed: IC4.46 (R4), R27.2
unnamed: IC4.47 (R3), R26.2
unnamed: IC4.48 (R2), R25.2
unnamed: R22.1, R23.2, Y2.1 (~ST)
SCI_MISO_0: IC4.4 (MISO/IO1); also elsewhere on the board
SCI_MOSI_0: IC4.5 (MOSI/IO0); also elsewhere on the board
SCI_SCK_0: IC4.3 (SCK); also elsewhere on the board
SCI_SS_0: IC4.6 (CS_N); also elsewhere on the board

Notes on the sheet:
Thinking of using either RA8876L4N or FT811Q. Looks like the FT811Q could be easier to get a hold of.
Place near VCC pins
Serial interface for the FT811 is SPI/QSPI. Other controls are interrupt (INTn) and Power down (PDn).
Seems to be connector both on the top and bottom of this. Probably best to have all components on the secondary side and have the LCD cable to through a hole. As long as the connectors are on the top side, then the connection should be OK.

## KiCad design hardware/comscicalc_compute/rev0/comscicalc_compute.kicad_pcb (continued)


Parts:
C11, C18, C21, C23: 100nF; C_0402_1005Metric; LCSC C1525
C12, C19, C25: 10uF; C_0805_2012Metric; LCSC C15850
C13, C15, C16, C17, C24, C27, C29: 22uF; C_0805_2012Metric; LCSC C45783
C14: 1uF; C_0603_1608Metric; LCSC C15849
C20: 4.7uF; C_0603_1608Metric; LCSC C19666
C22, C26, C28, C30: 10nF; C_0402_1005Metric; LCSC C15195
D1: NSR0240P2T5G; SODFL1006X40N; Mouser Part Number 863-NSR0240P2T5G
FB1, FB2: BLM21PG300SN1D; R_0805_2012Metric; LCSC C16903
FL1: ACM2012-361-2P-T002; ACM20121022PT001; Mouser Part Number 810-ACM20123612PT002
IC2: TPS92360DCKR; SOT65P210X110-5N; Mouser Part Number 595-TPS92360DCKR
IC3: AP62300TWU-7; SOT95P280X100-6N; Mouser Part Number 621-AP62300TWU-7
J3: USB4110-GF-A; USB4110GFA; Mouser Part Number 640-USB4110-GF-A
L1: ASPI-0403S-1R5M-T; ASPI0403S332MT; Mouser Part Number 815-ASPI-0403S-1R5M
L2: 3.3uH; IND_VLS5045EX-3R3N; LCSC C307875
R14, R18: 5.1k; R_0402_1005Metric; LCSC C258132
R15: 22R; R_0402_1005Metric; LCSC C25092
R16: 33.2k; R_0402_1005Metric; LCSC C400623
R17: 10k; R_0402_1005Metric; LCSC C25086
R19, R20: 1k; R_0402_1005Metric; LCSC C279981
R21: 10k; R_0402_1005Metric; LCSC C140214
SW2: SSSS211603; LCSC C125040
TP1, TP3, TP4, TP5, TP7: TestPoint; TestPoint_Pad_D1.5mm
U1: USBLC6-2SC6; SOT-23-6; LCSC C5250994

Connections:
+3V3: C11.1, C12.1, C13.1, C15.1, C20.1, C24.1, C26.1, C27.1, C28.1, C29.1, C30.1, FB1.1, IC2.5 (VIN), L1.2; also elsewhere on the board
/POWER/3V3_pre_filter: C16.1, C17.1, FB1.2, L2.1, R16.2
/POWER/24V_SW: D1.2, IC2.1 (SW), L1.1
/POWER/BST: C18.2, IC3.6 (BST)
/POWER/CC1: J3.A5, R14.1
/POWER/CC2: J3.B5, R18.1
/POWER/FB: IC3.4 (FB), R16.1, R17.2
/POWER/PWR_EN: IC3.5 (EN), R20.2, TP1.1
/POWER/SW: C18.1, IC3.2 (SW), L2.2
/POWER/USB_EMI_D_N: FL1.2, U1.4 (I/O2)
/POWER/USB_EMI_D_P: FL1.1, U1.6 (I/O1)
BACKLIGHT_DRIVE: C14.1, D1.1, TP4.1; also elsewhere on the board
BACKLIGHT_FB: IC2.3 (FB), R15.1, TP5.1; also elsewhere on the board
BACKLIGHT_PWM: IC2.4 (CTRL), R19.1, TP7.1; also elsewhere on the board
GND: C11.2, C12.2, C13.2, C14.2, C15.2, C16.2, C17.2, C19.2, C20.2, C21.2, C22.2, C23.2, C24.2, C25.2, C26.2, C27.2, C28.2, C29.2, C30.2, IC2.2 (GND), IC3.1 (GND), J3.A1, J3.A12, J3.B1, J3.B12, J3.MP1, J3.MP2, J3.MP3, J3.MP4, R14.2, R15.2, R17.1, R18.2, R19.2, SW2.1 (A), U1.2 (GND); also elsewhere on the board
unnamed: C21.1, R20.1, R21.2, SW2.2 (B)
USB_CONN_D_N: J3.A7, J3.B7, U1.3 (I/O2)
USB_CONN_D_P: J3.A6, J3.B6, U1.1 (I/O1)
USB_D_N: FL1.3; also elsewhere on the board
USB_D_P: FL1.4; also elsewhere on the board
USB_POWER: C19.1, C23.1, C25.1, FB2.2, IC3.3 (VIN), R21.1, TP3.1; also elsewhere on the board
USB_POWER_IN: C22.1, FB2.1, J3.A4, J3.A9, J3.B4, J3.B9, U1.5 (VBUS)

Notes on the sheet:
Test points
Cheap 5V - 3V3, max 3A.
USB ESD and EMI protection
3V3 to 24V LCD backlight
USB power filter
Bulk capacitance. To be spread out and placed near sinks.
USB 2.0, no PD (5V, max 3A) over USB-C
USB-C recepticle
VUSB to 3V3, max 3A.
Default USB-C power delivery Max 3A
Cheap step up to 24V for LCD backlight. Nominally draws max 40mA. IdcMax for ind. calc. to ~2A. With tolerance, choose > 2.5A The bigger the inductance, the lower the ripple current is. 4.7-10uH is recommended.


Board: 4 copper layers, 96.0 x 61.0 mm, 111 parts (0 on the bottom side), 123 nets.

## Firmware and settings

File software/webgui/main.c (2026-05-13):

#define CLAY_IMPLEMENTATION
#include "clay.h"
#include "gui.h"
#include "comscicalc.h"
#include <string.h>

// 4 MB static arena for Clay — avoids any JS-side arena management
#define CLAY_MEMORY_SIZE (6 * 1024 * 1024)
static uint8_t clayMemory[CLAY_MEMORY_SIZE];

// Written every frame by UpdateDrawFrame; JS reads it via GetRenderCommandArrayAddr
static Clay_RenderCommandArray renderCommands;

// Calculator state
static calcCoreState_t calcState;

#define INPUT_TEXT_LEN  512
#define RESULT_TEXT_LEN 128

static char inputText[INPUT_TEXT_LEN]  = "0";
static char hexText[RESULT_TEXT_LEN]   = "0x0";
static char decText[RESULT_TEXT_LEN]   = "0";
static char binText[RESULT_TEXT_LEN]   = "0b0";
static char settingsText[32]           = "DEC";

static const char *const baseNames[3] = { "DEC", "HEX", "BIN" };

static void refreshDisplayStrings(void) {
    int16_t syntaxIssuePos = -1;
    calc_funStatus_t status = calc_printBuffer(
        &calcState, inputText, INPUT_TEXT_LEN, &syntaxIssuePos);
    if (status != calc_funStatus_SUCCESS || inputText[0] == '\0') {
        inputText[0] = '0';
        inputText[1] = '\0';
    }
    convertResult(decText, calcState.result, &calcState.numberFormat, inputBase_DEC);
    convertResult(hexText, calcState.result, &calcState.numberFormat, inputBase_HEX);
    convertResult(binText, calcState.result, &calcState.numberFormat, inputBase_BIN);

    const char *name = baseNames[calcState.numberFormat.inputBase];
    size_t n = strlen(name);
    for (size_t i = 0; i <= n; i++) settingsText[i] = name[i];
}

// Called once from JS after the WASM module is loaded
CLAY_WASM_EXPORT("Init")
void Init(float width, float height) {
    Clay_Arena arena = Clay_CreateArenaWithCapacityAndMemory(
        sizeof(clayMemory), clayMemory);
    Clay_Initialize(arena, (Clay_Dimensions){width, height},
                    (Clay_ErrorHandler){0});

    calc_coreInit(&calcState);
    calcState.numberFormat.inputBase    = inputBase_DEC;
    calcState.numberFormat.numBits      = 64;
    calcState.numberFormat.sign         = false;
    calcState.numberFormat.inputFormat  = INPUT_FMT_INT;
    calcState.numberFormat.outputFormat = INPUT_FMT_INT;

    refreshDisplayStrings();
}

// Called from JS on each keypress
CLAY_WASM_EXPORT("AddInput")
void AddInput(int32_t charCode) {
    calc_addInput(&calcState, (char)charCode);
    calc_solver(&calcState);
    refreshDisplayStrings();
}

CLAY_WASM_EXPORT("Backspace")
void Backspace(void) {
    calc_removeInput(&calcState);
    calc_solver(&calcState);
    refreshDisplayStrings();
}

// Tab cycles DEC → HEX → BIN → DEC
CLAY_WASM_EXPORT("CycleBase")
void CycleBase(void) {
    calcState.numberFormat.inputBase =
        (inputBase_t)((calcState.numberFormat.inputBase + 1) % 3);
    calc_updateBase(&calcState);
    calc_solver(&calcState);
    refreshDisplayStrings();
}

// JS calls this once after Init to know where to read render commands
CLAY_WASM_EXPORT("GetRenderCommandArrayAddr")
Clay_RenderCommandArray *GetRenderCommandArrayAddr(void) {
    return &renderCommands;
}

// Called every animation frame from JS
CLAY_WASM_EXPORT("UpdateDrawFrame")
void UpdateDrawFrame(
    float width, float height,
    float mouseWheelX, float mouseWheelY,
    float mousePositionX, float mousePositionY,
    bool isTouchDown, bool isMouseDown,
    bool arrowKeyDownPressedThisFrame, bool arrowKeyUpPressedThisFrame,
    float deltaTime)
{
    Clay_SetLayoutDimensions((Clay_Dimensions){ width, height });
    Clay_SetPointerState((Clay_Vector2){ mousePositionX, mousePositionY },
                         isMouseDown || isTouchDown);
    Clay_UpdateScrollContainers(isTouchDown,
                                (Clay_Vector2){ mouseWheelX, mouseWheelY },
                                deltaTime);
    Clay_BeginLayout();
    mainScreen(inputText, hexText, decText, binText, settingsText, 0, 24, width, height);
    renderCommands = Clay_EndLayout();
}

int main(void) {
    return 0;
}

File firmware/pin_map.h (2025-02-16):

#ifndef PIN_MAP_H
#define PIN_MAP_H

/* ------------ DEVICE MAPPINGS ------------ */
// SPI0, used for connecting to LED
#define SPI0_MISO_PIN 0
#define SPI0_CSn_PIN 1
#define SPI0_SCLK_PIN 2
#define SPI0_MOSI_PIN 3

// I2C, Used for offboard I2C
#define SDA0_LED_PIN 4
#define SCL0_LED_PIN 5
#define LED_SDBn_PIN 16

// I2C, Used for offboard keyboard
#define SDA1_KBD_PIN 6
#define SCL1_KBD_PIN 7
#define KBD_INTn_PIN 8
#define KBD_RST_PIN 9

// UART
#define UART0_TX_PIN 12
#define UART0_RX_PIN 13

// FT81x non-SPI functions
#define FT81X_PDn_PIN 17
#define FT81X_INTn_PIN 18

// General purpose pins, reserved offboard use
#define GPIO10_PIN 10
#define GPIO11_PIN 11
#define NC_GPIO14_PIN 14
#define NC_GPIO15__PIN 15
#define GPIO19_PIN 19
#define GPIO20_PIN 20
#define GPIO21_PIN 21
#define GPIO22_PIN 22
#define GPIO23_PIN 23
#define GPIO24_PIN 24
#define GPIO25_PIN 25
#define GPIO26_PIN 26
#define GPIO27_PIN 27
#define GPIO28_PIN 28
#define GPIO29_PIN 29

/* ------------ FUNCTION MAPPINGS ------------ */
// SPI mappings to FT81x/EVE driver:
// #define EVE_CS SPI0_CSn_PIN
// #define EVE_PDN FT81X_PDn_PIN
// #define EVE_SCK SPI0_SCLK_PIN
// #define EVE_MOSI SPI0_MOSI_PIN
// #define EVE_MISO SPI0_MISO_PIN
// #define EVE_SPI spi0

// UART0 mappings and settings
#define UART0_BR 115200
#define UART0 uart0

#endif

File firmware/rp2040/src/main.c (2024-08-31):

/*
MIT License

Copyright (c) 2023 Oskar von Heideken

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
THE SOFTWARE IS PROVIDED "AS IS", WITHOUT WARRANTY OF ANY KIND, EXPRESS OR
IMPLIED, INCLUDING BUT NOT LIMITED TO THE WARRANTIES OF MERCHANTABILITY,
FITNESS FOR A PARTICULAR PURPOSE AND NONINFRINGEMENT. IN NO EVENT SHALL THE
AUTHORS OR COPYRIGHT HOLDERS BE LIABLE FOR ANY CLAIM, DAMAGES OR OTHER
LIABILITY, WHETHER IN AN ACTION OF CONTRACT, TORT OR OTHERWISE, ARISING FROM,
OUT OF OR IN CONNECTION WITH THE SOFTWARE OR THE USE OR OTHER DEALINGS IN THE
SOFTWARE.
*/

// C
#include <stdio.h>
#include <stdlib.h>

// Freertos:
#include "FreeRTOS.h"
#include "task.h"

// Comscicalc entry points
#include "firmware_common.h"

#if defined(RP2040)
// RP2040
#include "rp2040_utils.h"
#endif

/**
 * @brief This hook is called by FreeRTOS when an stack overflow error is
 * detected.
 */
void vApplicationStackOverflowHook(TaskHandle_t xTask, char *pcTaskName) {
    //
    // This function can not return, so loop forever.  Interrupts are disabled
    // on entry to this function, so no processor interrupts will interrupt
    // this loop.
    //
    // UARTprintf("\n\n======================WARNING======================\n");
    // UARTprintf("Task %s had a stack overflow :(", pcTaskName);
    // UARTprintf("\n\n===================================================\n");
    while (1) {
    }
}

/**
 * @brief This hook is called by FreeRTOS when an stack overflow error is
 * detected.
 */
void vApplicationMallocFailedHook(void) {
    //
    // This function can not return, so loop forever.  Interrupts are disabled
    // on entry to this function, so no processor interrupts will interrupt
    // this loop.
    //
    // UARTprintf("\n\n======================WARNING======================\n");
    // UARTprintf("Task %s had a stack overflow :(", pcTaskName);
    // UARTprintf("\n\n===================================================\n");
    while (1) {
    }
}
/*
 * RUNTIME START
 */
int main() {
    // Init MCU hardware
    mcuInit();

//#define TEST_DISPLAY
#ifdef TEST_DISPLAY
    // Start the display test task
    TaskHandle_t displayTestTask = NULL;
    xTaskCreate(displayTestThread, "DISPLAY_TEST_THREAD", 1000, (void *)1,
                tskIDLE_PRIORITY, &displayTestTask);

#else
    // Start the main thread
    TaskHandle_t mainThreadHandle = NULL;
    xTaskCreate(mainThread, "MAIN_TASK", 200, (void *)1, tskIDLE_PRIORITY,
                &mainThreadHandle);
#endif
    // Start scheduler
    vTaskStartScheduler();
}

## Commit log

2022-08-19 TM4C123GXL works with Adafruit 2050 display. Basic TI GRLIB functions implemented and tested.
    [BIOS.obj, empty.cfg, m3_Hwi_asm.obj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]
2022-08-19 Rotated the screen so that text now works as well. Did that using the settings, the 0,0 location is now at the top of the D7 pin on the Adafruit 2050
2022-08-22 Added UART terminal where chars from UART is shown on screen. Backspace implemented, but newline isn't.
    [BIOS.obj, empty.cfg, m3_Hwi_asm.obj]
2022-08-28 Starting to align to a final structure. Increasing heap to init faster, and write rectangles faster. Fixed a SPI bug where the max SPI transfer length was reached due to larger heap. Rectangle fill i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
    [empty.cfg]
2022-08-28 Creating tasks dynamically plus a bit of restructuring.
    [empty.cfg]
2022-08-31 Added a linked list into which characters can be entered. Have verified that adding at the end is possible. Left to do is to insert characters anywhere in the list, and adding functionality to remove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
    [BIOS.obj, empty.cfg, m3_Hwi_asm.obj]
2022-09-05 A few updates making the screen update a bit quicker. It's in an acceptable state for now, using SPI
2023-01-15 Moved linked list to it's own header files. Added python script as a mockup of the layout, to enable faster turnaround of the design and functionality of the device.
    [Conn_and_sw.kicad_sch, comSciCalc.kicad_pcb, comSciCalc.kicad_sch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]
2023-02-27 Decimal result parsing and calculation using eval working. String coloring depending on brackets working
2023-03-07 Started on the C library before the python implementation becomes too complete/advanced. Currently evaluating preceding operators and brackets.
2023-03-07 Removed preceding operator, reused same logic as brackets, makes list orientations much neater
2023-03-10 Restructured a bit, and re-wrote functions related to character input. Now passes tests to insert characters into strings
2023-03-13 Added function to print the list entries to a string
2023-03-13 Initial tests for brackets are passing. Changed to allow negative depth, this can be used for formatting later on. It doesn't make sense for calculations, but can alert the user.
2023-03-14 Minor changes to calc code, fixed a bracket issue. Pytest now works as a test harness. Minor changes to the C test code.
2023-03-21 Adding unity test framework
2023-03-21 Changed test framework. Again... Now using unity test in C, which seems to work fine.
2023-03-28 Fixed memory leak issue in normal use case. Added a logger which uses the -V flag in the run script, and added some parameters to the run script. Updated the readme to reflect the changes as well.
2023-04-01 Updated test case. Test coverage around 90%. Majority of missing coverage is are hard-to-test null checks, most of which indicate a broken entry list.
2023-05-08 added new version of pcb. Not routed
    [comscicalc.csv, comscicalc.kicad_pcb, comscicalc.kicad_sch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]
2023-05-12 Added a submodule for a display driver that looks nice
    [comscicalc.kicad_pcb]
2023-05-12 Added the display driver to be tested
2023-05-13 Initially works with the RudolphRiedel display driver
2023-05-13 Created a new workspace for the initial working code with the FT81x, ADAFRUIT 1680 and TM4C123GXL
    [BIOS.obj, empty.cfg, m3_Hwi_asm.obj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]
2023-05-20 Building with FreeRTOS and a proper driver on TI GCC compiler.
    [BIOS.obj, m3_Hwi_asm.obj]
2023-05-20 Added in latest version of display driver as well
2023-05-20 Basic console is working: TM4C123GXL virtual COM port (UART0), 115200 baud, 8-n-1, chars displaying on screen.
2023-05-22 Now solving and printing result. However as soon as an operator is introduced, there is a NULL pointer deref.
2023-05-29 A pesky break statement caused multiple non-solvable operators to double-free memory. Issue has been solved now.
    [main.c]
2023-05-30 Changing the color of the input now available. There is however a thread sync issue between the syntax error checker output and the rx buffer. These should be handled by the same sync, but isn't for 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
    [main.c]
2023-06-04 Custom fonts, and some minor fixes. However, seg fault in unit test now..
    [display.c, display.h, main.c]
2023-06-04 Unit tests are now running again, issue was a missing null check in the print function
2023-06-07 Included wrongfully untracked files in form of the updated logger files
    [uart_logger.c]
2023-06-10 Support for multiple RAM fonts, and correctly offset blinking cursor at the end
    [display.c, display.h, main.c]
2023-06-13 Formatting bugs solved: Cursor position on screen with large operator names fixed. Minor fixes to screen updating rate (less flickering). Other minor updates
    [display.c, main.c]
2023-07-09 Fixed an allocation issue: was missing to allocate strlen+1 to account for null terminator
    [display.c, display.h]
2023-07-12 Fixed a bug in the base conversion, and tested it on hardware again.
    [main.c]
2023-08-02 Added status bar to screen, and with that using two RAM fonts. Also resetting result to 0 if no input was given
    [display.c, display.h, main.c]
2023-08-04 Input display wrapping now works, including cursor. Found two bugs: two operators after each other are not marked as error, and there is a mem leak if very many operations are entered.
    [display.c, display.h, main.c]
2023-08-13 Fixed syntax issue that last fix added. Brackets were placed in the wrong position.
2023-08-13 Fixed issue where single number in bracket did not calculate, e.g. 70+(70). Put verbose back after long expression debugging. Added all tests back in test suite
2023-08-20 Floating and fixed point along with conversion finally works
    [display.c, display.h, main.c]
2023-08-25 Changed directory structure, diving up into hardware dependent (firmware) and hardware agnostic (software)
    [BIOS.obj, empty.cfg, m3_Hwi_asm.obj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]
2023-10-15 CMake file finally builds with actual linking etc. Haven't tested code yet due to needing to implement the SPI drivers etc.
2023-10-16 Added a crude UART which needs to be fully tested. Config was added using RASC, which is called using a script, and config code was copied from Renesas example
2023-10-16 Cleaned up the hardware side of things, added the rev0 of the HW and removed all other intermediate, non-ordered hardwares
    [Conn_and_sw.kicad_sch, LCD.kicad_sch, comSciCalc.kicad_pcb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]
2023-10-17 Trying to get UART up and running, but I only get to send one single char.. Also added code formatter after Renesas code gen
2023-10-19 Changing the configuration of the renesas MCU to align with FreeRTOS, hopefully almost there. Need to build the SPI interface for the display.
2023-10-20 Freertos and uart is running, but UART still has an issue with not waiting for completion before overwriting the fifo
    [main.c]
2023-10-20 UART TX now waits for TX to be completed when using Renesas MCU and logger.
2023-10-22 SPI works, but screen isn't really up and running with the Renesas MCU yet
2023-10-23 Added support for the 64 bit sprintf functions now as well by changing linker flags. I believe that the SPI write function takes a lot of time, so that will most likely need to be looked at.
2023-11-09 Updated to new Renesas debug version, and pached a memory leak in the UART printf function.
    [firmware_common.c]
2023-11-09 Added result print line wrap. It's now left centered, but that might be OK
2023-11-11 Added spaces in binary output. Note, for fixed point, this has not been fixed yet.
    [display.c, display.h]
2023-11-11 Fixed the result formatting so that it now displays right to left and top to bottom.
    [display.c, display.h]
2023-11-12 Added spacing on fixed point binary print as well.
2023-11-24 rev0 of hardware works fine with VBATT pin left open. Starting rev1 using rp2040
    [LCD.kicad_sch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]
2023-12-02 Made yet another revision of the hardware using the rp2040
    [LCD.kicad_sch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]
2024-04-29 Added hardware changes and some of the missing fonts
    [LCD.kicad_sch, comscicalc_compute.kicad_pcb, comscicalc_compute.kicad_sch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]
2024-07-08 Board according to this rev (v2) has been ordered from oshpark.
    [LCD.kicad_sch, adc.kicad_sch, buttons.kicad_sch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]
2024-08-28 Quick refactor, broke out the menu functionality into its own file since it's been growing quite a bit
    [display.c, display.h, menu.c]
2024-08-31 Fixed incorrect syntax issue formatting in functions
    [display.c, display.h]
2024-09-02 Printing multi-line items now works.
2024-09-02 Added support for printing from the functions pointed to by the menu. However, the menu printing function have some holes in it, it looks good now but it's not scalable atm
2024-09-09 Added firmware_common to code formatter, and fixed multi-line objects in the menu
    [display.c, firmware_common.c, menu.c]
2024-09-09 Fixed a minor formatting mistake, and added a small comic font
    [display.c]
2024-09-12 Finally fixed the menu layout the right way. Switched from evaluating per word to per line
    [display.c, menu.c]
2024-09-12 Added functions for displaying bit sizes, added newline support in menu, and some minor fixes to menu formatting
    [display.c, menu.c]
2024-09-19 Fixed a bug where the cursor would increase even though nothing was written, causing misalignment of new chars.
    [firmware_common.c]
2025-02-09 Removed pico-sdk submodule to change dir
2025-07-14 Minor fixes after fresh install. Added directory for webgui and basic application
    [main.c]

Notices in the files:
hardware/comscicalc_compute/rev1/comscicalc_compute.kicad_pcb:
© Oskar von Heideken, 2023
